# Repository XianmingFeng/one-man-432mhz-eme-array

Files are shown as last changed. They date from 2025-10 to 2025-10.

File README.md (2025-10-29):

# Portable 432MHz (70cm) EME Yagi Array

**A lightweight, tool-less, single-person-portable 2x2x14-element Yagi array for 432 MHz EME operations.**

---

[中文](/README_zh.md) | [Deutsche](/README_de.md) | [日本語](/README_ja.md)

## Overview

This project provides an open-source design for a 432 MHz (70cm) EME (Earth-Moon-Earth) antenna array. 

The motivation for this design stems from a personal need: the inability to install permanent antennas at home required all amateur radio equipment to be designed around portability. This antenna system is the solution for operators who must travel to the field to get on the air.

While traditional EME arrays are often large and permanently installed, this design focuses on achieving the minimum required gain for EME while prioritizing **portability, light weight, and rapid, single-person operation.**

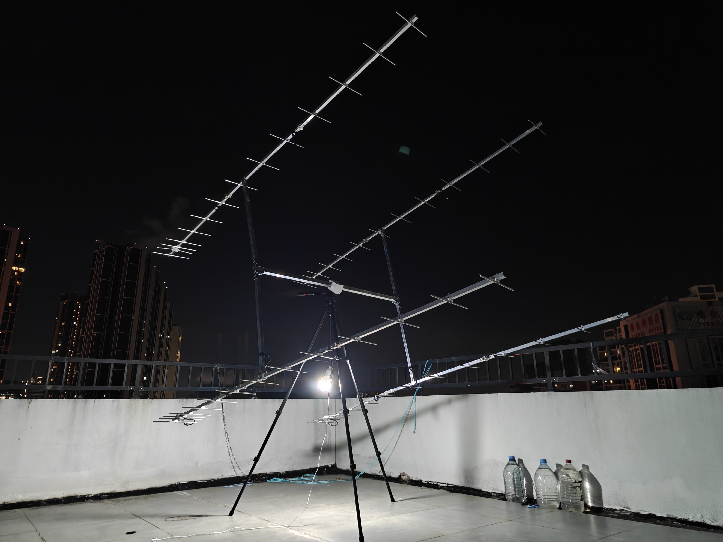
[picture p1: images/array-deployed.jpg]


## Proven Field Use & Air Travel

This system is not just a concept. Its usability was successfully confirmed during the **VK9QO Christmas Island DXpedition in 2025**.

The entire system is compliant with air travel requirements and can be checked as luggage. This makes it an ideal and proven solution for "Rovers" and DXpeditioners who wish to carry high-gain equipment to remote or rare DXCC entities to conduct EME operations.

## Key Features

* **Single-Person Portability:** The total weight of the entire array system, including the carrying bag, is **under 10 kg**.
* **Compact Storage:** All components are designed to be stored in a single fishing rod bag, making it easy for one person to carry.
* **Tool-less Assembly:** No tools (screwdrivers, wrenches, etc.) are required for field setup or teardown. The entire process can be completed by hand.
* **Rapid Deployment & Takedown:** The design is optimized for speed. This is achieved by:
    * Minimizing the number of loose parts.
    * Keeping most components connected as a single unit during storage.
    * Utilizing a simple "unfold-and-lock" and "unlock-and-fold" mechanism for deployment and retraction.

## Design Philosophy: Accessibility & Low Cost

A primary goal of this project is to enable anyone to easily build this antenna system. The design intentionally avoids complex machining processes (like CNC milling) to lower the barrier to entry.

Builders should be able to complete the entire antenna with only the most basic tools:
* Hand drill (pistol drill)
* Hand saw
* Manual rivet gun
* Pipe bender
* 3D Printer (All required `.step` files are available in the [`/CAD/3d_print`](/CAD/3d_print) directory)

**A note on 3D Printers:** We understand that not everyone owns a 3D printer. However:
1.  The accessibility and affordability of a home 3D printer are significantly higher than that of a home CNC machine.
2.  Even if you don't own one, using a 3D printing service is vastly more cost-effective and accessible than commissioning CNC machined parts.

## 3D Printing Guidelines

All 3D printed parts are located in the `/CAD/3d_print` directory.

### General Recommendations
Most parts function as mechanical components and are under moderate stress. The following general settings are recommended for strength and durability:

* **Material:** PETG (or ABS/ASA for better weather/UV resistance)
* **Layer Height:** 0.2mm
* **Wall Thickness:** 4 Layers
* **Infill Density:** 25% (or higher)
* **Infill Pattern:** Cross Hatch / Gyroid / or similar strong pattern

### **Critical Instructions**
**Each 3D print part subdirectory (e.g., `/CAD/3d_print/feed_box/`, `/CAD/3d_print/element_mount/`) now contains its own detailed, multi-lingual `README.md` file.**

You **MUST** read the specific `README.md` file in each part's directory before printing. These files contain essential, part-specific instructions for:
* Print Orientation
* Support settings (e.g., which parts require supports and which must not have them)
* Part-specific hardware (like heat-set inserts)

Failure to follow these part-specific instructions may result in parts that do not fit or function correctly.

## Aluminum Pipe Machining

All CAD files for the 6063 aluminum alloy tubes are located in the `/CAD/aluminum_pipe` directory. These parts form the foldable Yagi booms and the main H-frame.

### Manufacturing Methods
* **1. Manual (DIY) Machining:** Parts can be cut and drilled by hand. For this method, it is **ESSENTIAL** to 3D print and use the drilling jigs found in `/CAD/3d_print/drilling_jig/` to ensure all hinge and latch holes are aligned correctly.
* **2. Professional (CNC) Machining:** The provided `.step` files are CAM-ready and can be sent directly to a machining service for laser cutting or CNC milling.

### **Critical Instructions**
**A detailed, multi-lingual `README.md` with a full parts list, cutting dimensions, and drilling locations is located inside the [`/CAD/aluminum_pipe/`](/CAD/aluminum_pipe/) directory.**

You **MUST** read this file before cutting or drilling any metal. It contains all necessary specifications for the Yagi booms and H-frame components.

## Assembly Instructions

A step-by-step guide covering component fabrication (3D printing, aluminum machining), component preparation (coax cables), and sub-assembly (feed boxes) is now available.

**Please refer to the detailed Assembly Guide:**
**[`/instruction/README.md`](/instruction/README.md)**

This guide must be followed in order, as some steps produce tools required for later steps. The guide currently covers fabrication and initial sub-assemblies; final assembly steps will be added later.

## Technical Specifications

* **Band:** 432 MHz (70cm)
* **Array Configuration:** 2x2x14-element Yagi array (Four 14-element Yagis stacked in a 2x2 grid).
* **Polarization:** Horizontal.
* **Stacking Frame:** Custom H-frame.

### Theoretical Performance (Simulated)

**Single 14-el Yagi:**
* **Gain:** 16.38 dBi
* **Front-to-Back Ratio:** 33.02 dB
* **3dB Beamwidth (Horizontal):** 30.8°
* **3dB Beamwidth (Vertical):** 29.2°

**Full 2x2 Array:**
* **Gain:** 22.32 dBi
* **Front-to-Back Ratio:** 33.29 dB
* **3dB Beamwidth (Horizontal):** 14°
* **3dB Beamwidth (Vertical):** 13.2°
* **Antenna Temperature ($T_{ant}$):** 74.3 K
* **G/T Ratio:** 3.6 dB
> *Performance figures ($T_{ant}$, G/T) calculated assuming $T_{sky}$ = 27 K and $T_{earth}$ = 1800 K.*

## Mounting System (Tripod)

The array system is designed to be mounted on a standard tripod. The connection is made using the 3D printed part **`spearder_mount`** (files available in `/CAD/3d_print`).

This mount connects the array's H-frame to a tripod head's quick-release (QR) plate.

**Quick-Release Plate Requirements:**
The `spearder_mount` part is designed to be versatile. It is compatible with any long-slot style QR plate that meets these criteria:
* **Length:** Greater than 80mm.
* **Mounting:** Uses a long slot for the bolt (not a single fixed-position hole).
* **Bolt:** Compatible with a standard 1/4" (imperial) tripod bolt.

*As an example, the author uses a 38mm wide Arca-Swiss style QR plate paired with a fluid video head.*

**Tripod Recommendation:**
It is highly recommended to use a tripod with a **minimum height of 1.8 meters (approx. 6 feet)**.

* **Reason:** A tripod that is too short will cause the tail end of the antenna array to hit or drag on the ground when rotating to high elevation angles (e.g., tracking the moon).

## Design Details

### H-Frame Stacking System

The H-frame used to stack the four Yagis is designed for tool-less, rapid deployment. Its design is inspired by the folding leg mechanism of a portable table. This concept allows the frame to be deployed and locked into place, or unlocked and folded for storage, in seconds.

*The initial idea for this folding H-frame concept came from **BI1QGX**.*

### Modified 14-Element Yagi

The basic design of the 14-element Yagi is based on the **[GTV 70-14m by DG7YBN](https://dg7ybn.de/432MHz/GTV70_14.htm)**.
#### Electrical Design & Boom Correction

The electrical design adopts the data from DG7YBN and applies a Boom Correction (BC) factor to compensate for the effects of the conductive 20x20x1mm square aluminum boom. The elements are mounted 5mm above the boom (distance from the element's bottom to the boom's top surface).

The table below shows the original NEC free-space length (FL NEC), the final boom-corrected length (BC), and the required half-length (Half L) for element construction.

| \[mm\] | Diam | Pos Boom | FL NEC | BC | Half L |
|:---|:-----|:---|:---|:---|:---|
| Refl | 8 | 40 | 328 | 330.7 | 165.35 |
| DE | 10 | 144.5 | 313.4  | 316.1 | 158.05 |
| D1 | 8 | 193 | 309 | 311.7 | 155.85 |
| D2 | 8 | 286 | 304 | 306.7 | 153.35 |
| D3 | 8 | 468 | 292 | 294.7 | 147.35 |
| D4 | 8 | 681 | 286 | 288.7 | 144.35 |
| D5 | 8 | 928 | 282 | 284.7 | 142.35 |
| D6 | 8 | 1192 | 279 | 281.7 | 140.85 |
| D7 | 8 | 1477 | 274.5  | 277.2 | 138.6  |
| D8 | 8 | 1764 | 271 | 273.7 | 136.85 |
| D9 | 8 | 2054 | 268 | 270.7 | 135.35 |
| D10 | 8 | 2345 | 266 | 268.7 | 134.35 |
| D11 | 8 | 2627 | 264 | 266.7 | 133.35 |
| D12 | 8 | 2860 | 256 | 258.7 | 129.35 |

For a detailed explanation of the Boom Correction methodology, please visit [DG7YBN's BC page](https://dg7ybn.de/BC_numbers/BC.htm).

#### Mechanical Optimizations

In addition to the electrical design, this project introduces significant *mechanical* modifications to the original design to optimize it for portability and rapid assembly. These optimizations include:
* Redesigned boom segments and folding hinges.
* A new feedbox design.
* A specialized element mounting system (see below).

#### Element Mount (The `element_mount` part)

A key feature of this design is the 3D-printed element mount (`element_mount.step`) used for all parasitic elements (reflectors and directors).

* **Dual-Slot Design:** The part features two slots. One slot holds the element perpendicular to the boom for operation. A second slot, at a near-perpendicular angle, is used to hold the element in its folded (stowed) position.
* **Interference-Free Storage:** The "storage" slot is intentionally offset by a small angle (the `parking_angle`). This ensures that when folded, the elements do not lie perfectly parallel to the boom, preventing them from interfering with adjacent elements or the mounting bolt heads.
* **General-Purpose Parametric Design:** This element mount is a universal, general-purpose design, suitable for many Yagi projects using square booms and round elements. It has been released as its own **parametric OpenSCAD project**.

For full details, parameters (to adapt it for your own boom size, element diameter, storage angle, etc.), and `.scad` files, please see the dedicated project repository:
**[https://github.com/XianmingFeng/yagi_element_mounting](https://github.com/XianmingFeng/yagi_element_mounting)**

## Bill of Materials (BOM)

This is a partial BOM and will be updated as the project progresses.

| Category | Part | Qty |
|:---|:---|:----|
| Yagi Elements & Feedbox | `element_mount` 3D Printed Part | 52  |
| | Socket Head Cap Screw (Half-thread) M3x40 | 52  |
| | Wing Nut M3 | 56  |
| | `feed_box_front` 3D Printed Part | 4 |
| | `feed_box_middle` 3D Printed Part | 4 |
| | `feed_box_rear` 3D Printed Part | 4 |
| | `feed_box_isolator` 3D Printed Part | 4 |
| | Button Head Hex Socket Screw M3x8 | 8 |
| | Socket Head Cap Screw M3x40 | 4 |
| | Knurled Brass Nut (Heat-set Insert) M3x4x5 | 36  |
| | Socket Head Cap Screw M3x24 | 28  |
| | Copper Terminal Lug RNB-1.25-4 | 16  |
| | | |
| Yagi Boom Folding Mechanism | Small Double Spring Toggle Latch (No lock hole) | 8 |
| | Latch Catch A320B-0-2 | 8 |
| | Iron Gooseneck Hinge 20mm | 16  |
| | Round Head Blind Rivet M4x5 | 96  |
| | `boom_hinge_cap_front` 3D Printed Part | 8 |
| | `boom_hinge_cap_rear` 3D Printed Part | 8 |
| Boom-to-H-Frame Quick Release | Square Tube 2-Way T-Connector 25x25 | 4 |
| | Wing Bolt M6x30 | 4 |
| | Wing Nut M6 | 4 |
| | V-Spring Clip F5mm Single Pin (Hollow), L:37mm H:8mm | 4 |
| | Round Head Blind Rivet M5x8 | 8 |
| H-Frame Folding Mechanism | 90-Degree Folding Table Leg Hinge, Mini Size, Right  | 2 |
| | 90-Degree Folding Table Leg Hinge, Mini Size, Left | 2 |
| | Round Head Blind Rivet M5x6 | 24  |

## Repository Contents

* **`/CAD`**: Contains all 3D model files.
    * **`/CAD/3d_print`**: Contains `.step` files for all 3D printed parts. Each subdirectory (e.g., `feed_box/`, `element_mount/`) also contains a specific, multi-lingual `README.md` with detailed printing instructions. See the **3D Printing Guidelines** section above.
    * **`/CAD/aluminum_pipe`**: Contains `.step` files for all aluminum tube/pipe components. This directory now also contains a detailed **`README.md`** with machining instructions. See the **Aluminum Pipe Machining** section above.
* **`/images`**: Contains images used in this README.
* **`/instruction`**: Contains the detailed step-by-step assembly guide (`README.md` and translations).
* **`LICENSE`**: The project's open-source license file.
* **`README.md`**: This file (English).
* **`README_zh.md`**: Chinese translation.
* **`README_de.md`**: German translation.
* **`README_ja.md`**: Japanese translation.

## Project Status

* **Available Now:**
    * Initial 3D CAD files (`.step`) for all 3D printed parts and aluminum components are available in the `/CAD` directory.
    * Detailed, part-specific printing instructions are available in each `/CAD/3d_print` subdirectory.
    * Detailed machining instructions for aluminum parts are available in the `/CAD/aluminum_pipe/` directory.
    * Partial assembly instructions (covering fabrication and initial sub-assemblies) are available in the `/instruction/` directory.
    * Electrical design data (element lengths and positions) are in this README.
    * A partial Bill of Materials (BOM) is now available.
* **To Be Added:**
    * Complete Bill of Materials (BOM) (e.g., specific aluminum pipe sizes, screws).
    * Complete Assembly Instructions (final assembly, phasing lines) & Photos/Videos.
    * Simulation Files (e.g., EZNEC/4nec2).
    * Print-ready `.stl` files (recommended).
## Acknowledgements

* **DG7YBN** for the original [GTV 70-14m](https://dg7ybn.de/432MHz/GTV70_14.htm) antenna design and [Boom Correction methodology](https://dg7ybn.de/BC_numbers/BC.htm).
* **BI1QGX** for the foundational concept of the folding H-frame.

## License

Shield: [][cc-by-nc-sa]

This work is licensed under a
[Creative Commons Attribution-NonCommercial-ShareAlike 4.0 International License][cc-by-nc-sa].

[][cc-by-nc-sa]

[cc-by-nc-sa]: http://creativecommons.org/licenses/by-nc-sa/4.0/
[cc-by-nc-sa-image]: https://licensebuttons.net/l/by-nc-sa/4.0/88x31.png
[cc-by-nc-sa-shield]: https://img.shields.io/badge/License-CC%20BY--NC--SA%204.0-lightgrey.svg

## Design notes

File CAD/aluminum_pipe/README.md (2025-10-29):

# Aluminum Pipe Machining Instructions

[English](#english) | [中文 (Chinese)](#中文-chinese) | [Deutsche (German)](#deutsche-german) | [日本語 (Japanese)](#日本語-japanese)

---

## English

### Overview
This directory contains all `.step` CAD files for the 6063 aluminum alloy tubes required for the antenna array. These components form the foldable Yagi booms and the main H-shaped stacking frame.

All parts must be precisely cut to length and drilled. The provided `.step` files are dimensionally accurate and can be used for both manual (DIY) manufacturing and professional CAM processing.

### General Manufacturing Recommendations

There are two primary methods to manufacture these parts:

**1. Manual (DIY) Machining**
* Parts can be cut to length with a hand saw and drilled using a hand drill or drill press.
* **Drilling Jigs (CRITICAL):** For all critical hole alignments (e.g., hinge and latch holes on the booms, hinge holes on the H-frame), it is **ESSENTIAL** to 3D print and use the corresponding drilling jigs available in the `../3d_print/drilling_jig/` directory. This ensures all folding components align and operate smoothly.
    * Use `hinge_drill_jig.step` for Yagi boom sections.
    * Use `mast_drill_jig.step` for the vertical masts.
    * Use `spreader_drill_jig.step` for the horizontal spreader.

**2. Professional (CNC) Machining**
* The `.step` files provided are **CAM-ready**.
* You can send these files directly to a machining service (e.g., for laser cutting or CNC milling) for professional and highly accurate manufacturing.

---

### Bill of Materials (BOM) & Machining Details

#### Module 1: Yagi Antenna Booms (4 Assemblies total)
These components assemble to create four individual, three-section, foldable 14-element Yagis.

| Part File (STEP) | Material | Qty (per Array) | Description & Machining Notes |
|:---|:---|:---|:---|
| `yagi_boom_front.step`  | 20x20x1mm Square Tube | 4 | **Front Boom Section.** <br> • **Element Holes:** Spaced holes for antenna elements. <br> • **Hinge/Latch Holes:** Densely clustered holes at the ends for folding hinges and latches. <br> • **Jig:** Must use `hinge_drill_jig.step` for manual drilling of hinge/latch holes.  |
| `yagi_boom_middle.step` | 20x20x1mm Square Tube | 4 | **Middle Boom Section.** <br> • **Element Holes:** Spaced holes for antenna elements. <br> • **Hinge/Latch Holes:** Densely clustered holes at the ends for folding hinges and latches. <br> • **Jig:** Must use `hinge_drill_jig.step` for manual drilling of hinge/latch holes. |
| `yagi_boom_rear.step` | 20x20x1mm Square Tube | 4 | **Rear Boom Section.** <br> • **Element Holes:** Spaced holes for antenna elements. <br> • **Hinge/Latch Holes:** Densely clustered holes at the ends for folding hinges and latches. <br> • **Jig:** Must use `hinge_drill_jig.step` for manual drilling of hinge/latch holes. |

---
#### Module 2: H-Frame (Stacking Frame) (1 Assembly total)
These components form the main folding H-frame used to stack the four Yagi antennas.

| Part File (STEP) | Material | Qty (per Array) | Description & Machining Notes |
|:---|:---|:---|:---|
| `stacking_vertical_mast.step` | 25x25x1mm Square Tube | 4 | **Vertical Mast.** <br> • These four tubes form the two vertical "legs" of the H-frame. <br> • **Hinge Holes:** Holes at one end are for mounting the 90-degree folding hinges. <br> • **Jig:** Highly recommend using `mast_drill_jig.step` for manual drilling. |
| `stacking_horizontal_spreader.step` | 30x30x1mm Square Tube | 1 | **Horizontal Spreader.** <br> • This single, heavy-duty tube is the central horizontal spine that bears the weight of the entire array. <br> • **Hinge Holes:** Holes at both ends are for mounting the 90-degree folding hinges. <br> • **Jig:** Highly recommend using `spreader_drill_jig.step` for manual drilling. |

---
#### Module 3: Interface & Adapter Parts
This part serves as a shim or sleeve to ensure a tight fit between the booms and the mounting connectors.

| Part File (STEP) | Material | Qty (per Array) | Description & Machining Notes |
|:---|:---|:---|:---|
| `boom_sleeve.step` | 25x25x2.5mm Square Tube | 8 | **Boom Sleeve / Adapter.** <br> • This part adapts the 20x20mm Yagi boom to fit snugly inside the 25x25mm quick-release T-connectors. <br> • **Manufacture:** Simply cut the 25x25x2.5mm tube in half lengthwise (longitudinally). <br> • **Precision:** No high precision is required for this part. |

---
---

## 中文 (Chinese)

### 概览
此目录包含本天线阵列所需的所有 6063 铝合金管材的 `.step` CAD 文件。这些组件用于构成可折叠的八木天线主梁 (Yagi Booms) 和 H 型主支撑框架 (H-frame)。

所有零件都必须被精确地切割到指定长度并钻孔。所提供的 `.step` 文件尺寸精确，既可用于手动 (DIY) 制造，也可直接用于专业的 CAM 加工。

### 通用制造建议

有两种主要方法来制造这些零件：

**1. 手动 (DIY) 加工**
* 可以使用手锯切割长度，并使用手电钻或台钻钻孔。
* **钻孔夹具 (关键):** 对于所有关键的孔位对齐（例如，主梁上的铰链和锁扣孔，H 型框架上的铰链孔），**必须** 3D 打印并使用 `../3d_print/drilling_jig/` 目录中相应的钻孔夹具。这能确保所有折叠部件正确对齐且运行顺畅。
    * 八木主梁 (Yagi boom) 请使用 `hinge_drill_jig.step`。
    * 垂直梁 (Vertical mast) 请使用 `mast_drill_jig.step`。
    * 水平梁 (Horizontal spreader) 请使用 `spreader_drill_jig.step`。

**2. 专业 (CNC) 加工**
* 此目录中提供的 `.step` 文件是**符合 CAM 加工标准**的。
* 您可以将这些文件直接发送给机械加工服务商 (例如，激光切割或 CNC 铣削)，以进行专业且高精度的制造。

---

### 物料清单 (BOM) 与加工详情

#### 模块 1: 八木天线主梁 (Yagi Booms) (共 4 套)
这些组件用于组装成四根独立、三段式、可折叠的 14 单元八木天线。

| 零件文件 (STEP) | 材料 | 阵列所需数量 | 描述与加工说明 |
|:---|:---|:---|:---|
| `yagi_boom_front.step`  | 20x20x1mm 方管 | 4 | **主梁 - 前段。** <br> • **振子孔:** 沿主梁分布的孔洞，用于安装天线振子。 <br> • **铰链/锁扣孔:** 两端密集的孔洞，用于安装折叠铰链和弹簧锁扣。 <br> • **夹具:** 手动钻铰链/锁扣孔时，**必须**使用 `hinge_drill_jig.step`。 |
| `yagi_boom_middle.step` | 20x20x1mm 方管 | 4 | **主梁 - 中段。** <br> • **振子孔:** 沿主梁分布的孔洞，用于安装天线振子。 <br> • **铰链/锁扣孔:** 两端密集的孔洞，用于安装折叠铰链和弹簧锁扣。 <br> • **夹具:** 手动钻铰链/锁扣孔时，**必须**使用 `hinge_drill_jig.step`。 |
| `yagi_boom_rear.step` | 20x20x1mm 方管 | 4 | **主梁 - 后段。** <br> • **振子孔:** 沿主梁分布的孔洞，用于安装天线振子。 <br> • **铰链/锁扣孔:** 两端密集的孔洞，用于安装折叠铰链和弹簧锁扣。 <br> • **夹具:** 手动钻铰链/锁扣孔时，**必须**使用 `hinge_drill_jig.step`。 |

---
#### 模块 2: H型框架 (Stacking Frame) (共 1 套)
这些组件构成了用于堆叠四根八木天线的主折叠 H 型框架。

| 零件文件 (STEP) | 材料 | 阵列所需数量 | 描述与加工说明 |
|:---|:---|:---|:---|
| `stacking_vertical_mast.step` | 25x25x1mm 方管 | 4 | **H型架垂直梁。** <br> • 这四根管子组成了 H 型框架的两条垂直“腿”。 <br> • **铰链孔:** 一端的孔洞用于安装 90 度折叠“桌腿”铰链。 <br> • **夹具:** 手动钻孔时，**强烈建议**使用 `mast_drill_jig.step`。 |
| `stacking_horizontal_spreader.step` | 30x30x1mm 方管 | 1 | **H型架水平梁。** <br> • 这根单独的、加强的管材是 H 型架的中央水平脊柱，承载整个阵列的重量。 <br> • **铰链孔:** 两端的孔洞用于安装 90 度折叠“桌腿”铰链。 <br> • **夹具:** 手动钻孔时，**强烈建议**使用 `spreader_drill_jig.step`。 |

---
#### 模块 3: 转接与适配零件
此零件用作垫片或套筒，以确保主梁和安装连接件之间紧密配合。

| 零件文件 (STEP) | 材料 | 阵列所需数量 | 描述与加工说明 |
|:---|:---|:---|:---|
| `boom_sleeve.step` | 25x25x2.5mm 方管 | 8 | **主梁套筒 / 转接件。** <br> • 用于将 20x20mm 的八木主梁适配，使其能紧密安装在 25x25mm 内径的快装 T 型连接件中。 <br> • **制造:** 只需将 25x25x2.5mm 的管材沿长度方向（纵向）锯成两半。 <br> • **精度:** 此零件**没有高精度要求**。 |

---
---

## Deutsche (German)

### Übersicht
Dieses Verzeichnis enthält alle `.step` CAD-Dateien für die 6063-Aluminiumlegierungsrohre, die für das Antennen-Array benötigt werden. Diese Komponenten bilden die faltbaren Yagi-Antennenbäume und den H-förmigen Haupt-Stacking-Rahmen.

Alle Teile müssen präzise auf Länge zugeschnitten und gebohrt werden. Die bereitgestellten `.step`-Dateien sind maßgenau und können sowohl für die manuelle (DIY) Fertigung als auch für die professionelle CAM-Verarbeitung verwendet werden.

### Allgemeine Fertigungsempfehlungen

Es gibt zwei Hauptmethoden, um diese Teile herzustellen:

**1. Manuelle (DIY) Bearbeitung**
* Teile können mit einer Handsäge auf Länge geschnitten und mit einer Handbohrmaschine oder Ständerbohrmaschine gebohrt werden.
* **Bohrschablonen (ENTSCHEIDEND):** Für alle kritischen Lochausrichtungen (z. B. Scharnier- und Riegellöcher an den Booms, Scharnierlöcher am H-Rahmen) ist es **UNERLÄSSLICH**, die entsprechenden Bohrschablonen aus dem Verzeichnis `../3d_print/drilling_jig/` in 3D zu drucken und zu verwenden. Dies stellt sicher, dass alle Klappkomponenten ausgerichtet sind und reibungslos funktionieren.
    * Verwenden Sie `hinge_drill_jig.step` für die Yagi-Boom-Abschnitte.
    * Verwenden Sie `mast_drill_jig.step` für die vertikalen Masten.
    * Verwenden Sie `spreader_drill_jig.step` für die horizontale Traverse.

**2. Professionelle (CNC) Bearbeitung**
* Die bereitgestellten `.step`-Dateien sind **CAM-fähig**.
* Sie können diese Dateien direkt an einen Bearbeitungsservice (z. B. zum Laserschneiden oder CNC-Fräsen) senden, um sie professionell und präzise fertigen zu lassen.

---

### Stückliste (BOM) & Bearbeitungsdetails

#### Modul 1: Yagi-Antennenbäume (Insgesamt 4 Baugruppen)
Diese Komponenten werden zu vier einzelnen, dreiteiligen, faltbaren 14-Element-Yagis zusammengebaut.

| Bauteildatei (STEP) | Material | Menge (pro Array) | Beschreibung & Bearbeitungshinweise |
|:---|:---|:---|:---|
| `yagi_boom_front.step`  | 20x20x1mm Vierkantrohr | 4 | **Vorderer Boom-Abschnitt.** <br> • **Elementlöcher:** Löcher zur Montage der Antennenelemente. <br> • **Scharnier-/Riegellöcher:** Dichte Lochgruppen an den Enden für Klappscharniere und Riegel. <br> • **Bohrschablone:** Beim manuellen Bohren der Scharnier-/Riegellöcher muss `hinge_drill_jig.step` verwendet werden.  |
| `yagi_boom_middle.step` | 20x20x1mm Vierkantrohr | 4 | **Mittlerer Boom-Abschnitt.** <br> • **Elementlöcher:** Löcher zur Montage der Antennenelemente. <br> • **Scharnier-/Riegellöcher:** Dichte Lochgruppen an den Enden für Klappscharniere und Riegel. <br> • **Bohrschablone:** Beim manuellen Bohren der Scharnier-/Riegellöcher muss `hinge_drill_jig.step` verwendet werden. |
| `yagi_boom_rear.step` | 20x20x1mm Vierkantrohr | 4 | **Hinterer Boom-Abschnitt.** <br> • **Elementlöcher:** Löcher zur Montage der Antennenelemente. <br> • **Scharnier-/Riegellöcher:** Dichte Lochgruppen an den Enden für Klappscharniere und Riegel. <br> • **Bohrschablone:** Beim manuellen Bohren der Scharnier-/Riegellöcher muss `hinge_drill_jig.step` verwendet werden.  |

---
#### Modul 2: H-Rahmen (Stacking Frame) (Insgesamt 1 Baugruppe)
Diese Komponenten bilden den faltbaren Haupt-H-Rahmen, der zur Stapelung der vier Yagi-Antennen verwendet wird.

| Bauteildatei (STEP) | Material | Menge (pro Array) | Beschreibung & Bearbeitungshinweise |
|:---|:---|:---|:---|
| `stacking_vertical_mast.step` | 25x25x1mm Vierkantrohr | 4 | **Vertikaler Mast.** <br> • Diese vier Rohre bilden die beiden vertikalen "Beine" des H-Rahmens. <br> • **Scharnierlöcher:** Löcher an einem Ende zur Montage der 90-Grad-Klappscharniere. <br> • **Bohrschablone:** Beim manuellen Bohren wird dringend empfohlen, `mast_drill_jig.step` zu verwenden. |
| `stacking_horizontal_spreader.step` | 30x30x1mm Vierkantrohr | 1 | **Horizontale Traverse.** <br> • Dieses einzelne, hochbelastbare Rohr ist das zentrale horizontale Rückgrat, das das Gewicht des gesamten Arrays trägt. <br> • **Scharnierlöcher:** Löcher an beiden Enden zur Montage der 90-Grad-Klappscharniere. <br> • **Bohrschablone:** Beim manuellen Bohren wird dringend empfohlen, `spreader_drill_jig.step` zu verwenden. |

---
#### Modul 3: Schnittstellen- & Adapterteile
Dieses Teil dient als Distanzstück oder Hülse, um einen festen Sitz zwischen den Booms und den Montageverbindern zu gewährleisten.

| Bauteildatei (STEP) | Material | Menge (pro Array) | Beschreibung & Bearbeitungshinweise |
|:---|:---|:---|:---|
| `boom_sleeve.step`  | 25x25x2.5mm Vierkantrohr | 8 | **Boom-Hülse / Adapter.** <br> • Passt den 20x20mm Yagi-Boom an, damit er fest in die 25x25mm Schnellverschluss-T-Verbinder passt. <br> • **Herstellung:** Das 25x25x2.5mm Rohr einfach der Länge nach halbieren. <br> • **Präzision:** Für dieses Teil ist keine hohe Präzision erforderlich. |

---
---

## 日本語 (Japanese)

### 概要
このディレクトリには、アンテナアレイに必要なすべての 6063 アルミニウム合金チューブの `.step` CADファイルが含まれています。これらのコンポーネントは、折りたたみ式の八木アンテナブームと、H型メイン・スタッキングフレームを構成します。

すべての部品は、指定された長さに正確に切断し、穴あけ加工する必要があります。提供される `.step` ファイルは寸法が正確であり、手動 (DIY) での製造と、専門的なCAM（キャム）加工の両方に使用できます。

### 一般的な製造推奨事項

これらの部品を製造するには、主に2つの方法があります。

**1. 手動 (DIY) 加工**
* 部品は手鋸で長さに切断し、ハンドドリルやボール盤で穴をあけることができます。
* **穴あけ治具 (重要):** すべての重要な穴の位置合わせ（例: ブームのヒンジやラッチの穴、Hフレームのヒンジ穴）には、`../3d_print/drilling_jig/` ディレクトリにある対応する穴あけ治具を3Dプリントして**必ず使用**してください。これにより、すべての折りたたみコンポーネントが正しく位置合わせされ、スムーズに動作することが保証されます。
    * 八木ブーム（Yagi boom）には `hinge_drill_jig.step` を使用します。
    * 垂直マスト（Vertical mast）には `mast_drill_jig.step` を使用します。
    * 水平スプレッダー（Horizontal spreader）には `spreader_drill_jig.step` を使用します。

**2. 専門業者 (CNC) 加工**
* 提供されている `.step` ファイルは**CAM対応**です。
* これらのファイルを（レーザーカットやCNCフライス加工などの）機械加工サービスに直接送信して、専門的かつ高精度に製造してもらうことができます。

---

### 部品表 (BOM) と加工詳細

#### モジュール 1: 八木アンテナブーム (Yagi Booms) (合計 4 セット)
これらのコンポーネントは、4本（それぞれ3セクションで構成される）の折りたたみ式14エレメント八木アンテナを組み立てるために使用されます。

| パーツファイル (STEP) | 材質 | アレイあたりの数量 | 説明と加工ノート |
|:---|:---|:---|:---|
| `yagi_boom_front.step`  | 20x20x1mm 角パイプ | 4 | **ブーム - フロントセクション。** <br> • **エレメント用の穴:** アンテナエレメント（素子）を取り付けるための穴。 <br> • **ヒンジ/ラッチ用の穴:** 両端に集中している穴は、折りたたみヒンジとラッチ用。 <br> • **治具:** 手動でヒンジ/ラッチの穴をあける際は、**必ず** `hinge_drill_jig.step` を使用してください。 |
| `yagi_boom_middle.step` | 20x20x1mm 角パイプ | 4 | **ブーム - ミドルセクション。** <br> • **エレメント用の穴:** アンテナエレメント（素子）を取り付けるための穴。 <br> • **ヒンジ/ラッチ用の穴:** 両端に集中している穴は、折りたたみヒンジとラッチ用。 <br> • **治具:** 手動でヒンジ/ラッチの穴をあける際は、**必ず** `hinge_drill_jig.step` を使用してください。  |
| `yagi_boom_rear.step` | 20x20x1mm 角パイプ | 4 | **ブーム - リアセクション。** <br> • **エレメント用の穴:** アンテナエレメント（素子）を取り付けるための穴。 <br> • **ヒンジ/ラッチ用の穴:** 両端に集中している穴は、折りたたみヒンジとラッチ用。 <br> • **治具:** 手動でヒンジ/ラッチの穴をあける際は、**必ず** `hinge_drill_jig.step` を使用してください。 |

---
#### モジュール 2: Hフレーム (Stacking Frame) (合計 1 セット)
これらのコンポーネントは、4本の八木アンテナをスタックするために使用される、メインの折りたたみ式Hフレームを構成します。

| パーツファイル (STEP) | 材質 | アレイあたりの数量 | 説明と加工ノート |
|:---|:---|:---|:---|
| `stacking_vertical_mast.step` | 25x25x1mm 角パイプ | 4 | **垂直マスト。** <br> • これら4本のパイプがHフレームの2本の垂直な「脚」を構成します。 <br> • **ヒンジ用の穴:** 一方の端にある穴は、90度折りたたみヒンジを取り付けるためのものです。 <br> • **治具:** 手動で穴をあける際は、`mast_drill_jig.step` の使用を**強く推奨**します。 |
| `stacking_horizontal_spreader.step` | 30x30x1mm 角パイプ | 1 | **水平スプレッダー。** <br> • この1本の頑丈なパイプは、アレイ全体の重量を支える中央の水平な背骨となります。 <br> • **ヒンジ用の穴:** 両端にある穴は、90度折りたたみヒンジを取り付けるためのものです。 <br> • **治具:** 手動で穴をあける際は、`spreader_drill_jig.step` の使用を**強く推奨**します。 |

---
#### モジュール 3: インターフェースとアダプター部品
この部品は、ブームと取り付けコネクタ間の確実な固定を保証するためのシム（詰め物）またはスリーブとして機能します。

| パーツファイル (STEP) | 材質 | アレイあたりの数量 | 説明と加工ノート |
|:---|:---|:---|:---|
| `boom_sleeve.step` | 25x25x2.5mm 角パイプ | 8 | **ブームスリーブ / アダプター。** <br> • 20x20mmの八木ブームを、内径25x25mmのクイックリリースT型コネクタにぴったりと適合させます。 <br> • **製造:** 25x25x2.5mmのパイプを長手方向に沿って半分に切断するだけです。 <br> • **精度:** この部品に**高い精度は要求されません**。 |

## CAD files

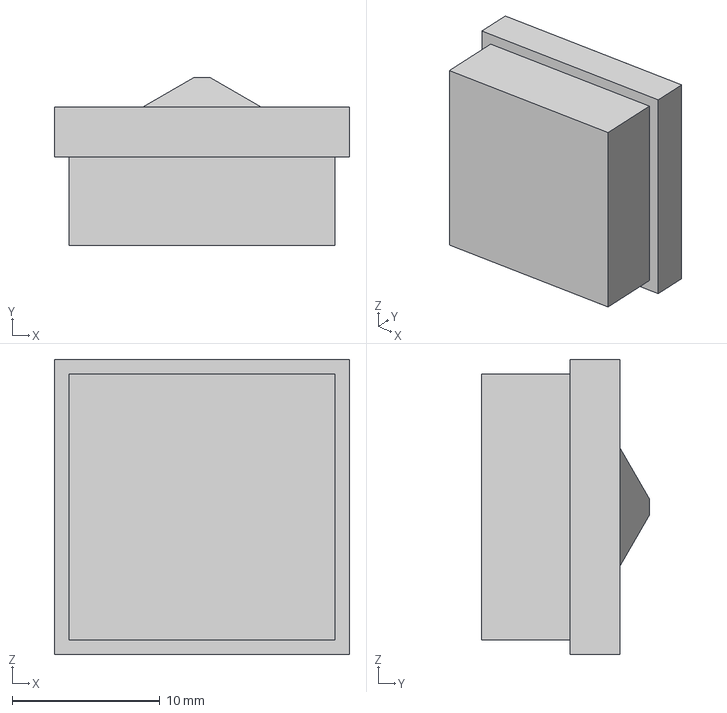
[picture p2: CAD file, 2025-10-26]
CAD/3d_print/boom_hinge/boom_hinge_cap_front.step
20.0 x 11.4 x 20.0 mm

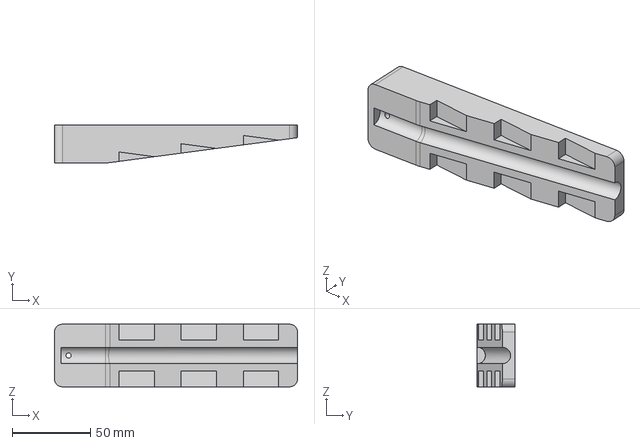
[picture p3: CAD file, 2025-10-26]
CAD/3d_print/drilling_jig/driven_element_drill_jig_upper.step
155.2 x 24.2 x 40.0 mm

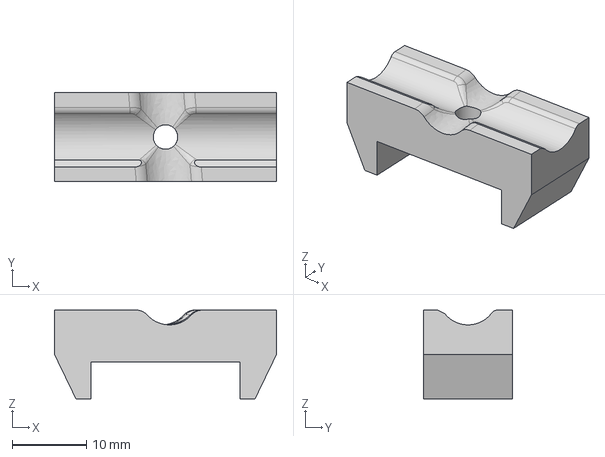
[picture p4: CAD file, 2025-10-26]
CAD/3d_print/element_mount/element_mount.step
30.0 x 12.0 x 12.0 mm

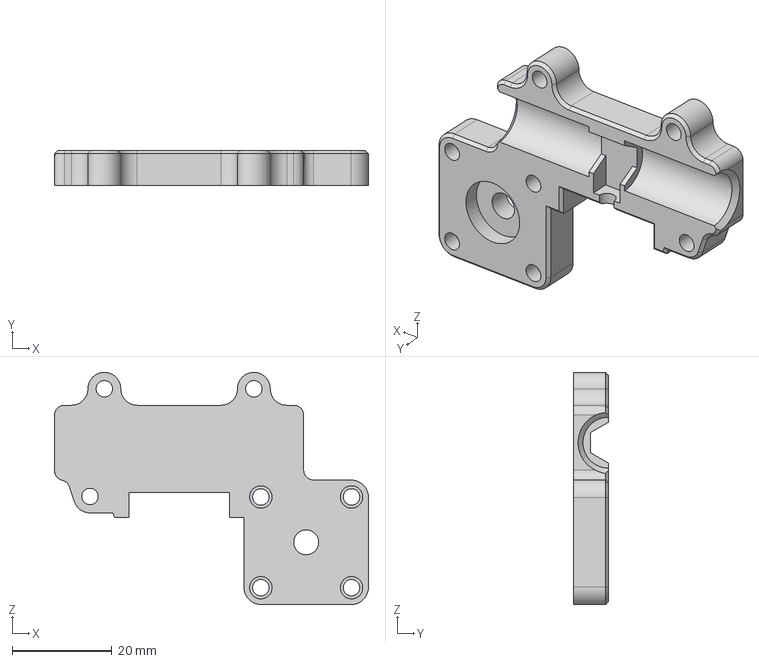
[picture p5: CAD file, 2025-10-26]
CAD/3d_print/feed_box/feed_box_rear.step
63.0 x 7.00 x 46.6 mm

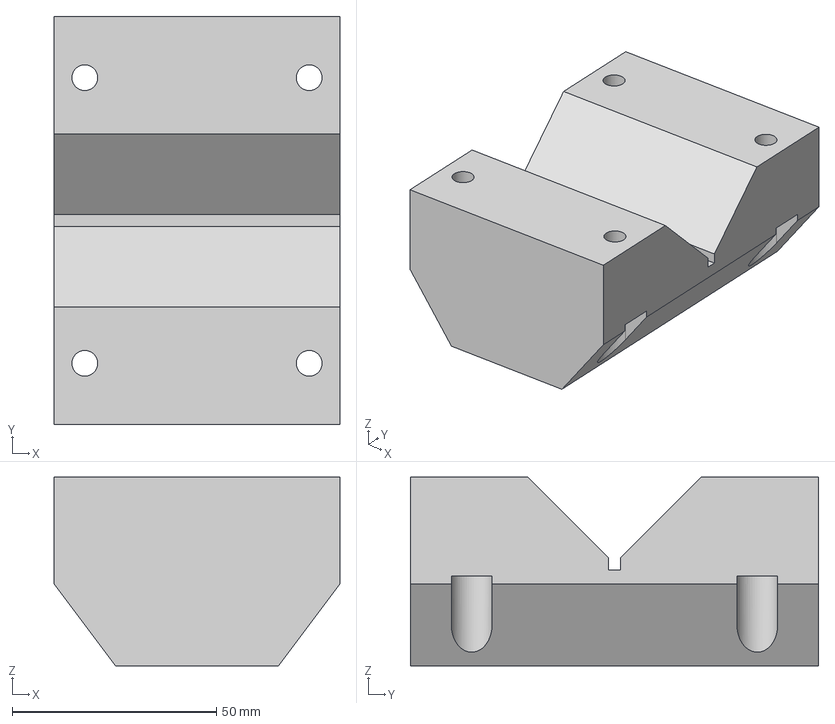
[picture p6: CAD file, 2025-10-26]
CAD/3d_print/spearder_mount/spearder_mount_lower.step
70.0 x 100.0 x 46.2 mm

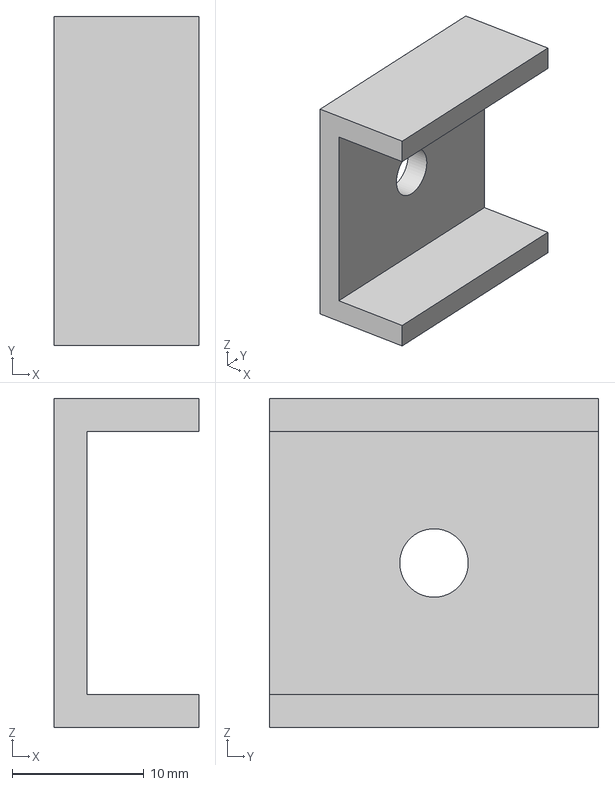
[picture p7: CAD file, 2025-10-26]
CAD/aluminum_pipe/boom_sleeve.step
11.0 x 25.0 x 25.0 mm

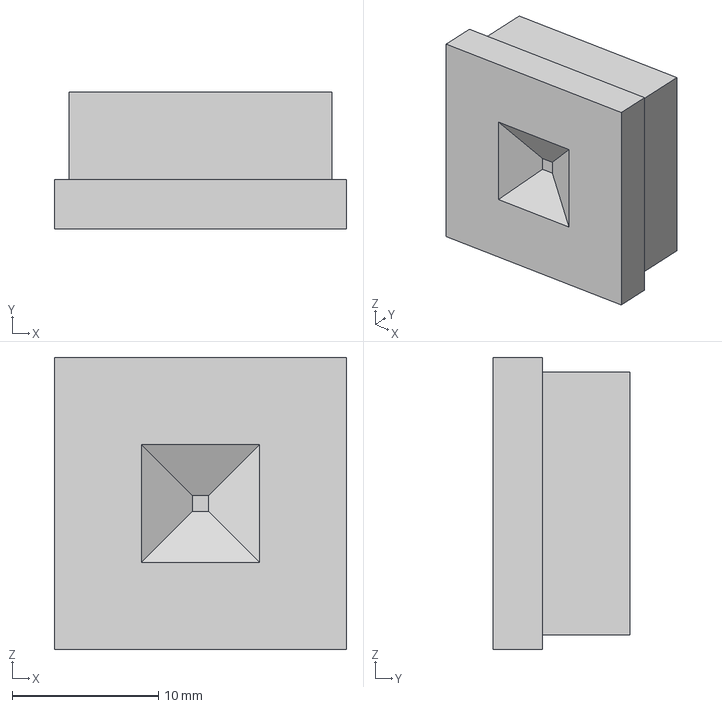
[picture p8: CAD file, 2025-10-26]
CAD/3d_print/boom_hinge/boom_hinge_cap_rear.step
20.0 x 9.40 x 20.0 mm

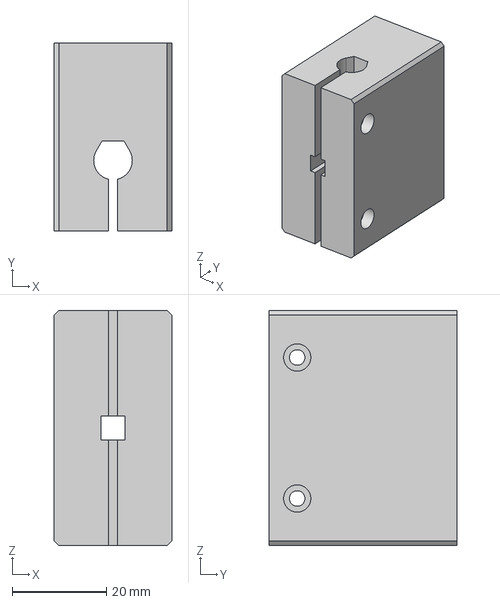
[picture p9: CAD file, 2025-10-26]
CAD/3d_print/drilling_jig/element_drill_jig.step
25.0 x 40.0 x 50.0 mm

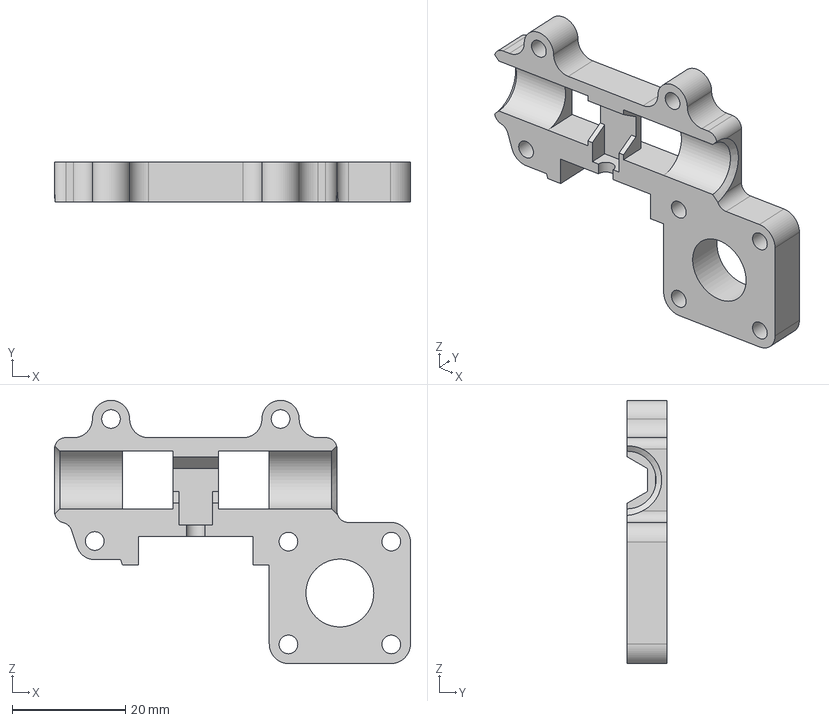
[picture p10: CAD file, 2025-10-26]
CAD/3d_print/feed_box/feed_box_middle.step
63.0 x 7.00 x 46.6 mm

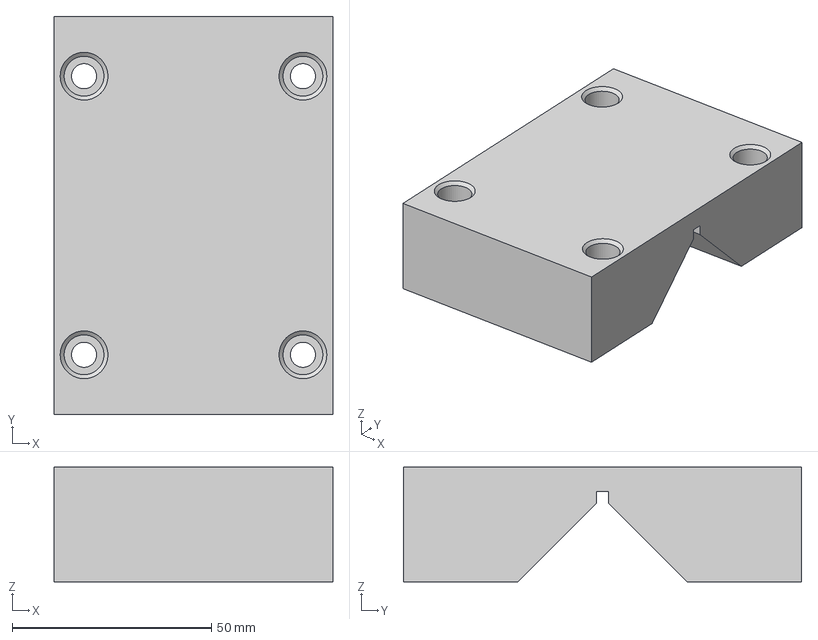
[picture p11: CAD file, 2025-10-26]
CAD/3d_print/spearder_mount/spearder_mount_upper.step
70.0 x 100.0 x 28.8 mm

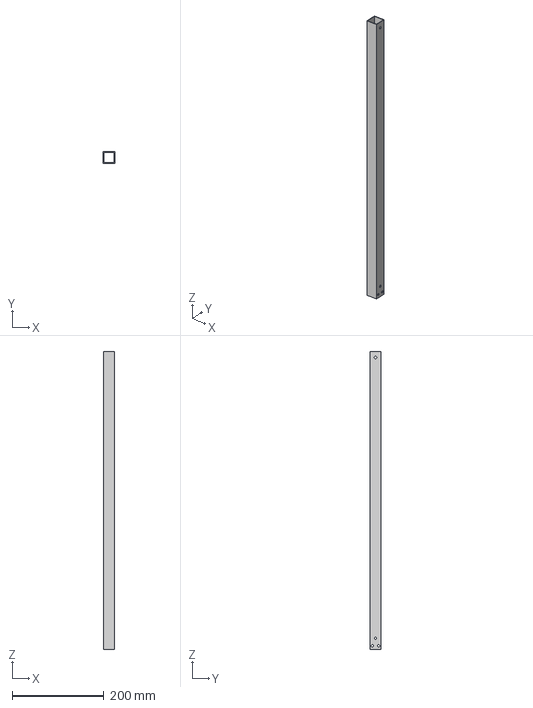
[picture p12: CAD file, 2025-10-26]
CAD/aluminum_pipe/stacking_vertical_mast.step
25.0 x 25.0 x 650.0 mm

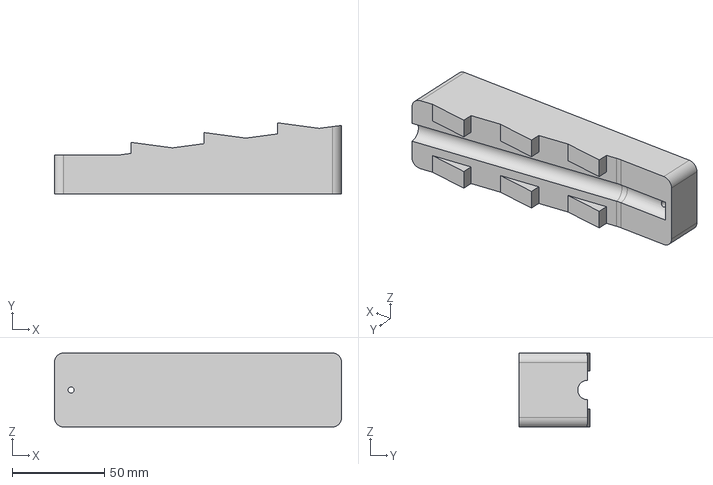
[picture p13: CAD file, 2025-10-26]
CAD/3d_print/drilling_jig/driven_element_drill_jig_lower.step
155.2 x 38.6 x 40.0 mm

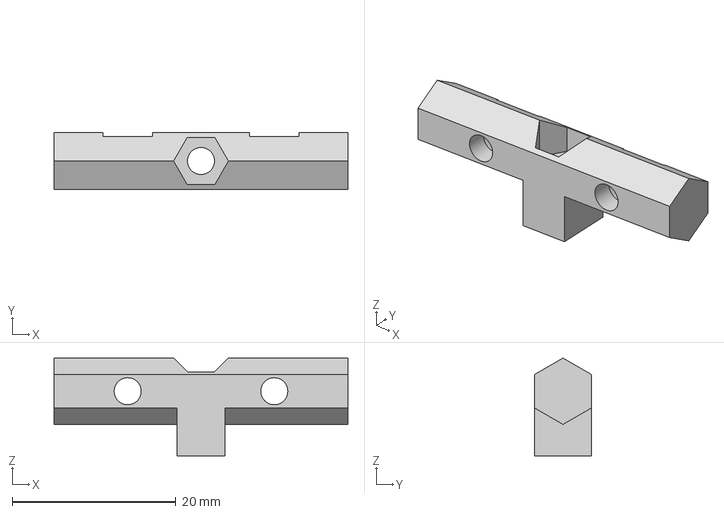
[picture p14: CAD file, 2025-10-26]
CAD/3d_print/feed_box/feed_box_isolator.step
35.9 x 7.01 x 11.9 mm

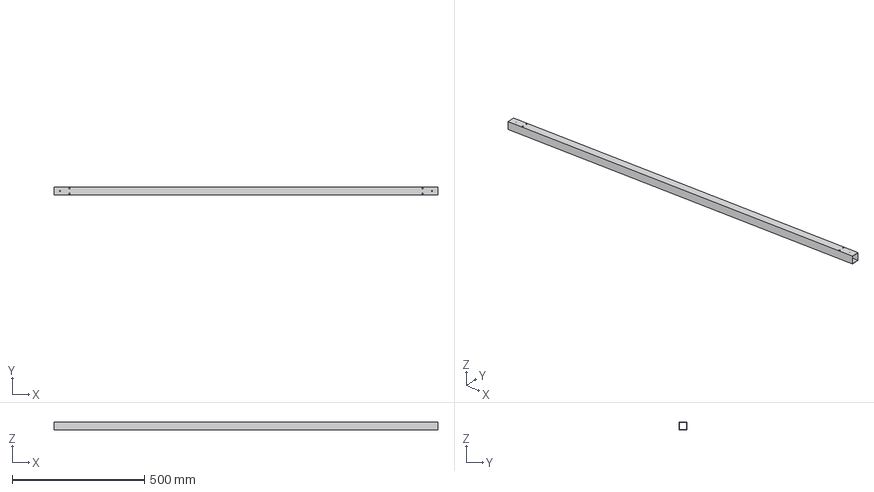
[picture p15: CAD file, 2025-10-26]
CAD/aluminum_pipe/stacking_horizontal_spreader.step
1450.0 x 30.0 x 30.0 mm

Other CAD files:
CAD/3d_print/feed_box/feed_box_front.step
CAD/aluminum_pipe/yagi_boom_middle.step
CAD/aluminum_pipe/yagi_boom_front.step
CAD/aluminum_pipe/yagi_boom_rear.step

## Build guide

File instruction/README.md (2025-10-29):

# Antenna Fabrication and Assembly Guide

## 1. Introduction

This document provides a step-by-step guide for fabricating and assembling all components for the Portable 432MHz EME Yagi Array.

**Critical Note:** Please follow these steps in the specified order. Some steps (like 3D printing) are required to create tools (jigs) needed for later steps (like aluminum machining).

For a complete Bill of Materials (BOM), please refer to the main [README.md](/README.md) file.

---

## 2. Required Tools

Before starting, ensure you have the following basic tools:

* 3D Printer
* Hand drill (pistol drill) or drill press
* Hand saw (for aluminum)
* Manual rivet gun
* Soldering iron (for installing heat-set inserts)
* Hex key (Allen wrench) set (M3)
* Wire stripper / Coax cable cutter
* Crimping tool (for RNB-1.25-4 lugs)
* Vector Network Analyzer (VNA) (Highly Recommended for verifying coax length)
* Permanent marker

---

## 3. Part 1: Component Fabrication

This section covers the creation of all custom parts from raw materials.

### Step 3.1: 3D Printing

This is the **first** fabrication step. The 3D-printed parts, especially the drilling jigs, are required for the aluminum machining.

1.  Navigate to the `/CAD/3d_print/` directory.
2.  Read the general printing guidelines in the main `README.md`.
3.  **Crucially**, read the specific `README.md` file *inside each subdirectory* (e.g., `feed_box/`, `element_mount/`, `drilling_jig/`) before printing. These files contain essential instructions on print orientation, supports, and required hardware.
4.  Print all required parts, paying special attention to the parts in the `drilling_jig/` directory, which are needed for Step 3.2.

> **IMPORTANT:** Failure to print the `drilling_jig` parts first will make accurate manual machining of the aluminum tubes extremely difficult.

### Step 3.2: Aluminum Machining

This step involves cutting and drilling all aluminum components for the elements, booms, and H-frame.

#### 3.2.1. Yagi Elements (Reflector & Directors)

Cut the parasitic elements (8mm diameter tubes) to their **full "Final BC Length"** specified in the table below. The "Drilling Midpoint" column indicates the **midpoint (center) of the element**, which is where you must drill the mounting hole.

Use the `element_drill_jig.step` (from the `../3d_print/drilling_jig/` directory) to ensure the hole is drilled precisely at the center. You will need to make 4 identical sets.

| Element | Qty (per Yagi) | Diam (mm) | **Cut Full Length (mm)** (Final BC Length) | **Drilling Midpoint (mm)** (Half L) |
|:---|:---|:---|:---|:---|
| Refl | 1 | 8 | 330.7 | 165.35 |
| D1 | 1 | 8 | 311.7 | 155.85 |
| D2 | 1 | 8 | 306.7 | 153.35 |
| D3 | 1 | 8 | 294.7 | 147.35 |
| D4 | 1 | 8 | 288.7 | 144.35 |
| D5 | 1 | 8 | 284.7 | 142.35 |
| D6 | 1 | 8 | 281.7 | 140.85 |
| D7 | 1 | 8 | 277.2 | 138.6 |
| D8 | 1 | 8 | 273.7 | 136.85 |
| D9 | 1 | 8 | 270.7 | 135.35 |
| D10 | 1 | 8 | 268.7 | 134.35 |
| D11 | 1 | 8 | 266.7 | 133.35 |
| D12 | 1 | 8 | 258.7 | 129.35 |

*Note: The Driven Element (DE) is a 10mm tube and is prepared as part of the Feed Box assembly (Part 5.1).*

#### 3.2.2. Yagi Booms & H-Frame

Machine the aluminum square tubes for the Yagi booms and the H-frame according to the `.step` files in the `/CAD/aluminum_pipe/` directory.

**Manufacturing Recommendations:**
* **Manual (DIY):** Cut parts with a hand saw and use a drill press. It is **ESSENTIAL** to use the 3D-printed jigs from the `/CAD/3d_print/drilling_jig/` directory (e.g., `hinge_drill_jig.step`, `mast_drill_jig.step`) for all hinge and alignment holes.
* **Professional (CNC):** The `.step` files are CAM-ready and can be sent directly to a machining service for laser cutting or CNC milling.

**Machining Summary:**

| Module | Part File(s) | Material | Qty | Key Machining Notes |
|:---|:---|:---|:---|:---|
| **Yagi Booms** | `yagi_boom_front.step`<br>`yagi_boom_middle.step`<br>`yagi_boom_rear.step` | 20x20x1mm Square Tube | 4 of each<br>(12 total) | • Cut to length as per STEP file.<br>• Drill element holes.<br>• **Critical:** Use `hinge_drill_jig.step` for all hinge/latch holes at the ends. |
| **H-Frame** | `stacking_vertical_mast.step` | 25x25x1mm Square Tube | 4 | • Forms the two vertical legs.<br>• **Critical:** Use `mast_drill_jig.step` for hinge holes. |
| **H-Frame** | `stacking_horizontal_spreader.step` | 30x30x1mm Square Tube | 1 | • The central horizontal spine.<br>• **Critical:** Use `spreader_drill_jig.step` for hinge holes. |
| **Adapters** | `boom_sleeve.step` | 25x25x2.5mm Square Tube | 8 | • Adapts 20mm boom to 25mm T-connector.<br>• **Manufacture:** Cut tube in half *lengthwise*. Low precision required. |

---

## 4. Part 2: Component Preparation

This section covers the preparation of off-the-shelf components before final assembly.

### Step 4.1: Coaxial Feedlines

Each of the four Yagis requires a 3/4 wavelength ($3/4 \lambda$) coaxial feedline (balun).

1.  **Verify Velocity Factor (VF):** The VF for SVY-50-3 coax is approximately **0.66**. For best results, use a VNA to measure the precise VF of your specific coax cable.
2.  **Calculate Length:** The formula is: $(\text{Wavelength} \times 0.75) \times \text{VF}$.
    * Example calculation: $(69.4 \text{ cm} \times 0.75) \times 0.66 = \mathbf{34.353 \text{ cm}}$
3.  **Cut Cables:** Cut **4** identical lengths of SVY-50-3 coax based on your calculation.
4.  **Prepare Ends (One Side):** On *one end* of each of the 4 cables:
    * Strip back ~1.5 cm of the outer jacket to expose the shield.
    * Carefully push the braided shield back, exposing the inner dielectric.
    * Strip back ~0.5 - 1 cm of the dielectric to expose the center core.
    * Twist the braided shield neatly into a single "pigtail."
5.  **Crimp Lugs:**
    * Crimp one **RNB-1.25-4** copper lug onto the center core.
    * Crimp one **RNB-1.25-4** copper lug onto the twisted shield pigtail.
    * You now have 4 coax cables, each with one end terminated in two lugs.

---

## 5. Part 3: Sub-Assembly

This section covers the assembly of the main modules.

### Step 5.1: Feed Box & Driven Element Assembly

This is a critical step that requires careful attention to detail. You will be building **two pairs** of mirrored feed boxes.

> **CRITICAL WARNING: Symmetrical Assembly Required**
>
> Because two Yagis mount "right-side up" and two mount "upside down" on the H-frame, you **MUST** build two "standard" feed boxes and two "mirrored" (symmetrical) feed boxes.
>
> If all four feed boxes are identical, two antennas will be 180° out of phase, and the array will **NOT** work.

To be clear, you must build two of each configuration shown below:

| Assembly Type | Quantity to Build | Wiring Configuration |
|:---|:---|:---|
| **"Standard" (L)** | 2 | **Center Core** $\rightarrow$ **Left** DE Half<br>**Shield** $\rightarrow$ **Right** DE Half |
| **"Mirrored" (R)** | 2 | **Center Core** $\rightarrow$ **Right** DE Half<br>**Shield** $\rightarrow$ **Left** DE Half |

#### Assembly Process:

1.  **Install Heat-Set Inserts:** Using a soldering iron, melt **M3x4x5** brass inserts into:
    * The bottom and both sides of the T-shaped `feed_box_middle` part.
    * The corresponding holes in the `feed_box_front` and `feed_box_rear` covers.
2.  **Install Center Bolt:**
    * Take one **M3x40** socket head cap screw.
    * Screw it down *from the top* of the T-part (`feed_box_middle`).
    * Thread it *through* the heat-set insert at the bottom of the T-part.
    * Tighten this screw firmly. It should be locked in place by the insert and not rotate.
3.  **Install Driven Element (DE):**
    * Insert the bent 10mm diameter aluminum tube (the Driven Element) into the T-part.
    * **CRITICAL ALIGNMENT:** Rotate the DE so that the *direction of its bend* is the *same* as the direction of the heat-set inserts on the sides of the T-part.
4.  **Connect Feedline:**
    * Take one of the prepared coax cables from Step 4.1.
    * Use two **M3x8** button head screws.
    * Feed the screws from the *opposite side* of the side-inserts (i.e., from the "inside" of the T-part).
    * Pass the screws through the holes in the Driven Element.
    * Attach the two crimped lugs (Core and Shield) to the screws.
5.  **FINAL CHECK (Standard vs. Mirrored):**
    * **For 2 assemblies:** Attach the **Center Core** lug to the **Left** DE half and the **Shield** lug to the **Right** DE half.
    * **For the other 2 assemblies:** Attach the **Center Core** lug to the **Right** DE half and the **Shield** lug to the **Left** DE half.
6.  **Mark Assemblies:** Use a permanent marker to clearly label the "Standard" and "Mirrored" assemblies (e.g., "L" and "R") so you do not mix them up during final assembly.

---

*(Tutorial sections below will be added based on future information)*

### Step 5.2: Yagi Boom Assembly (Hinges & Mounts)

*(Instructions for attaching hinges, latches, and 3D-printed caps to the boom sections to be added here.)*

### Step 5.3: Parasitic Element Installation

*(Instructions for attaching the 52 `element_mount` parts and the elements to the booms to be added here.)*

---

## 6. Part 4: Final Assembly

### Step 6.1: H-Frame Assembly

*(Instructions for assembling the vertical and horizontal H-frame parts with the 90-degree folding hinges to be added here.)*

### Step 6.2: Mounting Yagis to H-Frame

*(Instructions for mounting the four Yagi assemblies to the H-frame quick-release connectors to be added here.)*

### Step 6.3: Connecting Phasing Lines

*(Instructions for connecting the four feed boxes to the power divider/phasing harness to be added here.)*

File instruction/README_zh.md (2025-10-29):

# 天线加工与装配指南

## 1. 简介

本文档提供了便携式 432MHz EME 八木天线阵列所有组件的详细加工和装配步骤。

**重要提示：** 请严格按照本文档指定的顺序执行。某些步骤（如3D打印）是后续步骤（如铝管加工）所需工具（钻孔工装）的前提。

完整的物料清单 (BOM)，请参阅项目主 [README.md](/README.md) 文件。

---

## 2. 所需工具

在开始之前，请确保您拥有以下基本工具：

* 3D 打印机
* 手电钻或台钻
* 手锯（用于切割铝材）
* 手动拉铆枪
* 电烙铁（用于安装热熔螺母）
* M3 内六角扳手
* 剥线钳 / 同轴电缆剪
* 压线钳（用于 RNB-1.25-4 端子）
* 矢量网络分析仪 (VNA)（强烈推荐，用于精确测量馈线）
* 记号笔

---

## 3. 第一部分：零件加工

本节涵盖了所有定制零件的从零开始的制造过程。

### 步骤 3.1：3D打印

这是加工的**第一步**。3D打印的零件，特别是钻孔工装（drilling jigs），是后续铝管加工所必需的。

1.  进入 `/CAD/3d_print/` 目录。
2.  阅读主 `README.md` 文件中的通用打印建议。
3.  **关键：** 在打印前，请务必阅读**每个子目录中**特定的 `README.md` 文件（例如 `feed_box/`、`element_mount/`、`drilling_jig/`）。这些文件包含了关于打印方向、支撑和所需五金件的重要说明。
4.  打印所有需要的零件，特别注意 `drilling_jig/` 目录中的零件，它们是步骤 3.2 所必需的。

> **重要提示：** 如果不首先打印 `drilling_jig` 零件，后续对铝管的精确手动钻孔将变得极其困难。

### 步骤 3.2：铝管加工

此步骤包括切割和钻孔构成振子、主梁和H型框架的所有铝制部件。

#### 3.2.1. 八木天线振子 (反射器 & 引导器)

根据下表，将 8mm 直径的铝管切割成**完整的“最终 BC 长度”**。表中的“钻孔中点”列实际上是指振子的**中点位置（半长）**，您必须在此位置钻安装孔。

请使用 `../3d_print/drilling_jig/` 目录中的 `element_drill_jig.step` 工装来确保钻孔位置精确位于中心。您需要制作4套完全相同的振子。

| 振子 | 数量 (每根八木) | 直径 (mm) | **切割全长 (mm)** (最终 BC 长度) | **钻孔中点 (mm)** (半长) |
|:---|:---|:---|:---|:---|
| Refl (反射器) | 1 | 8 | 330.7 | 165.35 |
| D1 | 1 | 8 | 311.7 | 155.85 |
| D2 | 1 | 8 | 306.7 | 153.35 |
| D3 | 1 | 8 | 294.7 | 147.35 |
| D4 | 1 | 8 | 288.7 | 144.35 |
| D5 | 1 | 8 | 284.7 | 142.35 |
| D6 | 1 | 8 | 281.7 | 140.85 |
| D7 | 1 | 8 | 277.2 | 138.6 |
| D8 | 1 | 8 | 273.7 | 136.85 |
| D9 | 1 | 8 | 270.7 | 135.35 |
| D10 | 1 | 8 | 268.7 | 134.35 |
| D11 | 1 | 8 | 266.7 | 133.35 |
| D12 | 1 | 8 | 258.7 | 129.35 |

*注意：激励振子 (DE) 是 10mm 铝管，它将在馈电盒装配（第 5.1 部分）中单独准备。*

#### 3.2.2. 八木主梁 (Booms) & H型框架 (H-Frame)

根据 `/CAD/aluminum_pipe/` 目录中的 `.step` 文件，加工用于八木主梁和H型框架的铝方管。

**加工建议:**
* **手动 (DIY):** 使用手锯切割，并使用台钻钻孔。**至关重要：** 必须使用 `/CAD/3d_print/drilling_jig/` 目录中 3D 打印的工装（如 `hinge_drill_jig.step`, `mast_drill_jig.step` 等）来钻所有铰链和对齐孔。
* **专业 (CNC):** `.step` 文件是 CAM 就绪的，可直接发送给加工服务商进行激光切割或 CNC 铣削。

**加工概要:**

| 模块 | 零件文件 | 材料 | 数量 | 关键加工说明 |
|:---|:---|:---|:---|:---|
| **八木主梁** | `yagi_boom_front.step`<br>`yagi_boom_middle.step`<br>`yagi_boom_rear.step` | 20x20x1mm 方管 | 每种 4 个<br>(共 12 个) | • 按 STEP 文件切割长度。<br>• 钻振子孔。<br>• **关键:** 在末端使用 `hinge_drill_jig.step` 钻所有铰链/锁扣孔。 |
| **H型框架** | `stacking_vertical_mast.step` | 25x25x1mm 方管 | 4 | • 构成两条垂直 "腿"。<br>• **关键:** 使用 `mast_drill_jig.step` 钻铰链孔。 |
| **H型框架** | `stacking_horizontal_spreader.step` | 30x30x1mm 方管 | 1 | • 中央水平脊柱。<br>• **关键:** 使用 `spreader_drill_jig.step` 钻铰链孔。 |
| **适配器**  | `boom_sleeve.step` | 25x25x2.5mm 方管 | 8 | • 用于将 20mm 主梁适配到 25mm T型接头。<br>• **制造:** 沿长度方向将管子切成两半。精度要求不高。 |

---

## 4. 第二部分：组件准备

本节涵盖了在最终组装前对标准组件的预处理。

### 步骤 4.1：同轴馈线

每根八木天线都需要一条 3/4 波长 ($3/4 \lambda$) 的同轴馈线（兼作巴伦）。

1.  **确认速度系数 (VF):** SVY-50-3 同轴电缆的速度系数 (VF) 约为 **0.66**。为获得最佳效果，请使用 VNA 测量您手中电缆的精确 VF。
2.  **计算长度:** 公式为： $(\text{波长} \times 0.75) \times \text{VF}$。
    * 示例计算: $(69.4 \text{ cm} \times 0.75) \times 0.66 = \mathbf{34.353 \text{ cm}}$
3.  **裁剪电缆:** 根据您的计算，裁剪 **4** 根长度完全相同的 SVY-50-3 电缆。
4.  **处理末端 (一侧):** 在每根电缆的*一端*进行如下处理：
    * 剥去约 1.5 cm 的外护套，露出屏蔽层。
    * 小心地将编织屏蔽网向后推，露出内部介电层。
    * 剥去约 0.5 - 1 cm 的介电层，露出中心芯线。
    * 将编织屏蔽网整齐地捻成一股。
5.  **压接端子:**
    * 将一个 **RNB-1.25-4** 铜鼻子压接到中心芯线上。
    * 将一个 **RNB-1.25-4** 铜鼻子压接到捻成一股的屏蔽网上。
    * 现在您应有4根馈线，每根的一端都已端接好两个压线端子。

---

## 5. 第三部分：子组件装配

本节涵盖了主要模块的组装。

### 步骤 5.1：馈电盒与激励振子装配

这是关键一步，需要格外小心。您将需要制作**两对**镜像对称的馈电盒。

> **严重警告：必须对称装配**
>
> 由于两根八木天线 "正向" 安装在H架上，另外两根 "反向" (上下颠倒) 安装，您**必须**制作两个 "标准" 馈电盒和两个 "镜像" (对称) 馈电盒。
>
> 如果所有四个馈电盒都完全相同，将导致两根天线的相位相差 180°，阵列将**无法工作**。

为清晰起见，您必须按下表所示，每种配置各制作两个：

| 装配类型 | 制作数量 | 接线配置 |
|:---|:-----|:---|
| **"标准" (L)** | 2 | **芯线** $\rightarrow$ **左侧**激励振子<br>**屏蔽层** $\rightarrow$ **右侧**激励振子 |
| **"镜像" (R)** | 2 | **芯线** $\rightarrow$ **右侧**激励振子<br>**屏蔽层** $\rightarrow$ **左侧**激励振子 |

#### 装配流程:

1.  **安装热熔螺母:** 使用电烙铁，将 **M3x4x5** 铜螺母热熔进：
    * T 形零件 `feed_box_middle` 的底部和两侧沉孔。
    * `feed_box_front` (前盖) 和 `feed_box_rear` (后盖) 上的对应沉孔。
2.  **安装中心螺栓:**
    * 取一根 **M3x40** 杯头内六角螺栓。
    * 从 T 形零件 (`feed_box_middle`) 的顶部旋入。
    * 使其穿过 T 形零件底部的热熔螺母。
    * 拧紧这根螺栓。它应该被底部的螺母锁死，无法转动或松动。
3.  **安装激励振子 (DE):**
    * 将折弯好的 10mm 直径铝管（激励振子）插入 T 形零件中。
    * **关键对齐：** 旋转激励振子，使其*弯曲的方向*与 T 形零件两侧热熔螺母的*方向保持一致*。
4.  **连接馈线:**
    * 取一根步骤 4.1 中准备好的同轴馈线。
    * 使用两颗 **M3x8** 圆头内六角螺栓。
    * 将螺栓从侧面螺母的*反侧*（即 T 形零件的“内部”）穿入。
    * 使螺栓穿过激励振子上的孔。
    * 将两个压接端子（芯线和屏蔽层）分别固定在螺栓上。
5.  **最终检查 (标准 vs 镜像):**
    * **对于 2 个组件：** 将**芯线**端子连接到**左侧**激励振子，**屏蔽层**端子连接到**右侧**。
    * **对于另外 2 个组件：** 将**芯线**端子连接到**右侧**激励振子，**屏蔽层**端子连接到**左侧**。
6.  **标记组件:** 使用记号笔在 "标准" 和 "镜像" 组件上做好清晰标记（例如 "L" 和 "R"），以免在总装时混淆。

---

*(以下教程部分将根据未来的信息补充)*

### 步骤 5.2：八木主梁装配 (铰链与锁扣)

*(此处将添加关于将铰链、锁扣和3D打印端盖安装到主梁各分段的说明。)*

### 步骤 5.3：无源振子安装

*(此处将添加关于将 52 个 `element_mount` 部件和振子安装到主梁上的说明。)*

---

## 6. 第四部分：最终总装

### 步骤 6.1：H型框架装配

*(此处将添加关于使用90度折叠铰链组装H型框架垂直立柱和水平横梁的说明。)*

### 
步骤 6.2：安装八木天线至H型框架

*(此处将添加关于将四套八木天线组件安装到H型框架快速释放连接件上的说明。)*

### 步骤 6.3：连接相位线

*(此处将添加关于将四个馈电盒连接到功分器/相位匹配网络的说明。)*

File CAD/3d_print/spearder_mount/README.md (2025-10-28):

# Printing Instructions

[English](#english) | [中文 (Chinese)](#中文-chinese) | [Deutsche (German)](#deutsche-german) | [日本語 (Japanese)](#日本語-japanese)

---

## English

### Parts
* `spearder_mount_lower.step`
* `spearder_mount_upper.step`

### Purpose
These parts connect the entire antenna array (H-frame) to a tripod's quick-release (QR) plate.

### ⚠️ Critical Note
These are critical load-bearing components that support the entire array. They will be under **very high stress** during use. It is **strongly recommended** to print these parts at or above the following specifications to prevent failure.

### Recommended Print Settings
(These settings apply to both parts)

| Parameter | Value |
|:---|:---|
| **Material** | PETG |
| **Nozzle Diameter** | 0.4mm |
| **Layer Height** | 0.2mm |
| **Wall Thickness**  | 6 Layers |
| **Top Layers** | 5 Layers |
| **Bottom Layers** | 5 Layers |
| **Infill Density**  | 30% |
| **Infill Pattern**  | Cross Hatch |

### Orientation & Supports
* **Orientation:** Place the large rectangular flat side down on the print bed. The "V-shaped" groove should face upwards.
* **Supports:** **Must be enabled.**

---

## 中文 (Chinese)

### 零件
* `spearder_mount_lower.step`
* `spearder_mount_upper.step`

### 用途
这些零件用于将整个天线阵列 (H-Frame) 固定到三脚架的快装板 (QR Plate) 上。

### ⚠️ 重要提示
这些是关键的承力部件，用于支撑整个天线阵列，在使用中会承受**非常大的力**。为了防止失效，**强烈建议**使用以下推荐参数或更高规格进行打印。

### 推荐打印参数
(以下参数适用于两个零件)

| 参数 | 数值 |
|:---|:---|
| **材料** | PETG |
| **喷嘴直径** | 0.4mm |
| **层高** | 0.2mm |
| **壁厚** | 6 层 |
| **顶部层数** | 5 层 |
| **底部层数** | 5 层 |
| **填充密度** | 30% |
| **填充图案** | 交叉层叠 (Cross Hatch) |

### 打印方向与支撑
* **打印方向:** 将大的长方形平面朝下放置在打印床上，V 字凹槽朝上。
* **支撑:** **必须启用支撑。**

---

## Deutsche (German)

### Bauteile
* `spearder_mount_lower.step`
* `spearder_mount_upper.step`

### Zweck
Diese Teile verbinden die gesamte Antennenanordnung (H-Rahmen) mit der Schnellwechselplatte (QR-Platte) eines Stativs.

### ⚠️ Wichtiger Hinweis
Dies sind kritische, tragende Komponenten, die die gesamte Anordnung halten. Sie stehen während des Gebrauchs unter **sehr hoher Belastung**. Es wird **dringend empfohlen**, diese Teile mit den folgenden oder höheren Spezifikationen zu drucken, um ein Versagen zu verhindern.

### Empfohlene Druckeinstellungen
(Diese Einstellungen gelten für beide Bauteile)

| Parameter | Wert |
|:---|:---|
| **Material** | PETG |
| **Düsendurchmesser** | 0.4mm |
| **Schichthöhe** | 0.2mm |
| **Wandstärke** | 6 Schichten |
| **Obere Schichten**  | 5 Schichten |
| **Untere Schichten** | 5 Schichten |
| **Fülldichte** | 30% |
| **Füllmuster** | Cross Hatch |

### Ausrichtung & Stützstrukturen
* **Ausrichtung:** Legen Sie die große, rechteckige flache Seite nach unten auf das Druckbett. Die "V-förmige" Nut sollte nach oben zeigen.
* **Stützstrukturen:** **Müssen aktiviert sein.**

---

## 日本語 (Japanese)

### パーツ
* `spearder_mount_lower.step`
* `spearder_mount_upper.step`

### 目的
これらのパーツは、アンテナアレイ全体（Hフレーム）を三脚のクイックリリース（QR）プレートに接続するために使用されます。

### ⚠️ 重要事項
これらはアレイ全体を支える重要な耐荷重部品です。使用時には**非常に高い応力**がかかります。破損を防ぐため、これらのパーツは以下の推奨仕様またはそれ以上で印刷することを**強く推奨します**。

### 推奨印刷設定
（これらの設定は両方のパーツに適用されます）

| パラメータ | 値 |
|:---|:---|
| **素材** | PETG |
| **ノズル径** | 0.4mm |
| **積層ピッチ**  | 0.2mm |
| **壁の厚さ** | 6 層 |
| **上部レイヤー** | 5 層 |
| **底部レイヤー** | 5 層 |
| **充填密度** | 30% |
| **充填パターン** | クロスハッチ (Cross Hatch) |

### 配置とサポート
* **配置:** 大きな長方形の平らな面をプリントベッド側（下）に向け、「V字型」の溝が上を向くように配置してください。
* **サポート:** **有効にする必要があります。**

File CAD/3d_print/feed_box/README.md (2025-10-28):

# Printing Instructions

[English](#english) | [中文 (Chinese)](#中文-chinese) | [Deutsche (German)](#deutsche-german) | [日本語 (Japanese)](#日本語-japanese)

---

## English

### Parts
* `feed_box_front.step`
* `feed_box_middle.step`
* `feed_box_rear.step`
* `feed_box_isolator.step`

### Purpose
These parts assemble into a weatherproof box for the antenna's feed point. This box protects the feed point, secures the driven element, and holds the feedline connector (e.g., N-type connector). It consists of three shell components and one T-shaped isolator.

### Note
These parts are under moderate stress. The following general-purpose mechanical part settings are recommended.

### Recommended General Print Settings
The following settings apply to **all four parts** in this directory. Part-specific instructions for orientation and supports are listed below.

| Parameter | Value |
|:---|:---|
| **Material** | PETG |
| **Nozzle Diameter** | 0.4mm |
| **Layer Height** | 0.2mm |
| **Wall Thickness**  | 4 Layers |
| **Top Layers** | 4 Layers |
| **Bottom Layers** | 4 Layers |
| **Infill Density**  | 25% |
| **Infill Pattern**  | Cross Hatch |

---

### Part-Specific Instructions

#### 1. `feed_box_front`
* **Orientation:** Place the large flat face down on the print bed. The square opening should face upwards.
* **Supports:** **Manual (Custom) Supports Required.**
    * **Enable supports** *only* for the three countersunk "steps" (which are for the heat-set brass nuts).
    * **Disable supports** for all other areas. Note that the small groove (for the N-connector's waterproof O-ring) also **does not require support**.

#### 2. `feed_box_middle`
* **Orientation:** Place the large flat face down on the print bed. The semi-cylindrical groove should face upwards.
* **Supports:** **Must be enabled.**

#### 3. `feed_box_rear`
* **Orientation:** Place the large flat face down on the print bed. The semi-cylindrical groove should face upwards.
* **Supports:** **Must be enabled.**

#### 4. `feed_box_isolator`
* **Orientation:** Lay the part flat on the bed (in its "T" shape).
* **Supports:** **Not required.**

---
---

## 中文 (Chinese)

### 零件
* `feed_box_front.step`
* `feed_box_middle.step`
* `feed_box_rear.step`
* `feed_box_isolator.step`

### 用途
这些零件用于组装成一个馈电点防水盒。它用于保护馈电点、固定激励振子，并固定馈线连接座 (例如 N 型连接器)。它由三个外壳零件和一个 T 字形的绝缘零件组成。

### 注意
这些零件承受中等强度的受力，建议使用以下通用的机械零件参数进行打印。

### 推荐的通用打印参数
以下参数适用于此文件夹中的**所有四个零件**。每个零件特定的打印方向和支撑设置请见下方。

| 参数 | 数值 |
|:---|:---|
| **材料** | PETG |
| **喷嘴直径** | 0.4mm |
| **层高** | 0.2mm |
| **壁厚** | 4 层 |
| **顶部层数** | 4 层 |
| **底部层数** | 4 层 |
| **填充密度** | 25% |
| **填充图案** | 交叉层叠 (Cross Hatch) |

---

### 零件专属设置

#### 1. `feed_box_front`
* **打印方向:** 将大平面朝下放置在打印床上，方形槽口朝上。
* **支撑:** **需要手动绘制支撑 (Custom Supports)**。
    * **仅**为 3 个用于嵌入铜螺母的沉孔台阶**启用支撑**。
    * 在所有其他位置**禁用支撑**。请注意，用于安装 N 型连接器 (N-type connector) 防水O形圈的凹槽也**无须支撑**。

#### 2. `feed_box_middle`
* **打印方向:** 将大平面朝下放置在打印床上，半圆柱凹槽朝上。
* **支撑:** **必须启用支撑**。

#### 3. `feed_box_rear`
* **打印方向:** 将大平面朝下放置在打印床上，半圆柱凹槽朝上。
* **支撑:** **必须启用支撑**。

#### 4. `feed_box_isolator`
* **打印方向:** 将零件 T 字形平放在打印床上。
* **支撑:** **无须开启支撑。**

---
---

## Deutsche (German)

### Bauteile
* `feed_box_front.step`
* `feed_box_middle.step`
* `feed_box_rear.step`
* `feed_box_isolator.step`

### Zweck
Diese Teile werden zu einer wetterfesten Box für den Speisepunkt der Antenne zusammengebaut. Diese Box schützt den Speisepunkt, fixiert das Erregerelement und hält den Speiseleitungsanschluss (z. B. N-Buchse). Sie besteht aus drei Gehäusekomponenten und einem T-förmigen Isolator.

### Hinweis
Diese Teile sind einer mäßigen Belastung ausgesetzt. Die folgenden Einstellungen für mechanische Standardbauteile werden empfohlen.

### Empfohlene Allgemeine Druckeinstellungen
Die folgenden Einstellungen gelten für **alle vier Bauteile** in diesem Verzeichnis. Teilespezifische Anweisungen zur Ausrichtung und zu Stützstrukturen sind unten aufgeführt.

| Parameter | Wert |
|:---|:---|
| **Material** | PETG |
| **Düsendurchmesser** | 0.4mm |
| **Schichthöhe** | 0.2mm |
| **Wandstärke** | 4 Schichten |
| **Obere Schichten**  | 4 Schichten |
| **Untere Schichten** | 4 Schichten |
| **Fülldichte** | 25% |
| **Füllmuster** | Cross Hatch |

---

### Teilespezifische Anweisungen

#### 1. `feed_box_front`
* **Ausrichtung:** Legen Sie die große, flache Seite nach unten auf das Druckbett. Die quadratische Öffnung sollte nach oben zeigen.
* **Stützstrukturen:** **Manuelle (benutzerdefinierte) Stützstrukturen erforderlich.**
    * Stützstrukturen **nur** für die drei Senkungen (Stufen) **aktivieren**, die für die Messing-Gewindeeinsätze vorgesehen sind.
    * Stützstrukturen für alle anderen Bereiche **deaktivieren**. Beachten Sie, dass die kleine Nut (für den wasserdichten O-Ring des N-Steckers) ebenfalls **keine Stützstruktur benötigt**.

#### 2. `feed_box_middle`
* **Ausrichtung:** Legen Sie die große, flache Seite nach unten auf das Druckbett. Die halbzylindrische Nut sollte nach oben zeigen.
* **Stützstrukturen:** **Müssen aktiviert sein.**

#### 3. `feed_box_rear`
* **Ausrichtung:** Legen Sie die große, flache Seite nach unten auf das Druckbett. Die halbzylindrische Nut sollte nach oben zeigen.
* **Stützstrukturen:** **Müssen aktiviert sein.**

#### 4. `feed_box_isolator`
* **Ausrichtung:** Legen Sie das Teil flach (in seiner "T"-Form) auf das Druckbett.
* **Stützstrukturen:** **Nicht erforderlich.**

---
---

## 日本語 (Japanese)

### パーツ
* `feed_box_front.step`
* `feed_box_middle.step`
* `feed_box_rear.step`
* `feed_box_isolator.step`

### 目的
これらのパーツは、アンテナの給電点用の耐候性ボックス（防水箱）を構成します。このボックスは給電点を保護し、給電素子を固定し、給電コネクタ（N型コネクタなど）を保持します。3つのシェルパーツと1つのT字型絶縁パーツで構成されています。

### 注意
これらのパーツには中程度の負荷がかかります。以下の一般的な機械部品用の設定で印刷することを推奨します。

### 推奨共通印刷設定
以下の設定は、このディレクトリ内の**4つのパーツすべて**に適用されます。パーツごとの配置とサポートに関する指示は、下記を参照してください。

| パラメータ | 値 |
|:---|:---|
| **素材** | PETG |
| **ノズル径** | 0.4mm |
| **積層ピッチ**  | 0.2mm |
| **壁の厚さ** | 4 層 |
| **上部レイヤー** | 4 層 |
| **底部レイヤー** | 4 層 |
| **充填密度** | 25% |
| **充填パターン** | クロスハッチ (Cross Hatch) |

---

### パーツ別設定

#### 1. `feed_box_front`
* **配置:** 大きな平らな面をプリントベッド側（下）に向け、四角い開口部が上を向くように配置します。
* **サポート:** **手動（カスタム）サポートが必要**です。
    * 熱圧入ナット用の3つの皿穴（段差部分）**にのみサポートを有効**にしてください。
    * 他のすべての領域ではサポートを**無効**にしてください。なお、N型コネクタの防水Oリング用の小さな溝も**サポート不要**です。

#### 2. `feed_box_middle`
* **配置:** 大きな平らな面をプリントベッド側（下）に向け、半円筒形の溝が上を向くように配置します。
* **サポート:** **有効にする必要があります。**

#### 3. `feed_box_rear`
* **配置:** 大きな平らな面をプリントベッド側（下）に向け、半円筒形の溝が上を向くように配置します。
* **サポート:** **有効にする必要があります。**

#### 4. `feed_box_isolator`
* **配置:** パーツを「T」の字になるように平らにプリントベッドに配置します。
* **サポート:** **不要です。**

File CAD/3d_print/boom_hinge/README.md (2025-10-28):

# Printing Instructions

[English](#english) | [中文 (Chinese)](#中文-chinese) | [Deutsche (German)](#deutsche-german) | [日本語 (Japanese)](#日本語-japanese)

---

## English

### Parts
* `boom_hinge_cap_front.step`
* `boom_hinge_cap_rear.step`

### Purpose
These parts are installed at the Yagi boom's folding hinge. They serve to align the boom segments and fill the gap at the pivot.

### ⚠️ Critical Note
These components are under **significant pressure** during assembly and use. It is **strongly recommended** to print them with thick walls as specified below. Insufficient wall thickness will cause the parts to crack and become lodged inside the boom, making them impossible to remove.

### Recommended Print Settings

| Parameter | Value |
|:---|:---|
| **Material** | PETG |
| **Nozzle Diameter** | 0.4mm |
| **Layer Height** | 0.2mm |
| **Wall Thickness**  | 5 Layers |
| **Top Layers** | 6 Layers |
| **Bottom Layers** | 5 Layers |
| **Infill Density**  | 40% |
| **Infill Pattern**  | Cross Hatch |

### Orientation & Supports
* **Orientation:** Place the large flat side down on the print bed. The concave and convex features should face upwards.
* **Supports:** **Supports must be enabled.**

---

## 中文 (Chinese)

### 零件
* `boom_hinge_cap_front.step`
* `boom_hinge_cap_rear.step`

### 用途
这两个零件用于安装在八木 (Yagi) 主梁的折叠处。它们用于对齐主梁位置，并填补转轴处的隙间。

### ⚠️ 重要提示
这些零件在安装和使用中会承受**较大的压力**。**强烈建议**使用以下指定的厚壁参数来打印它们。如果壁厚不足，会导致零件在安装时破裂并卡在主梁内部，从而无法取出。

### 推荐打印参数

| 参数 | 数值 |
|:---|:---|
| **材料** | PETG |
| **喷嘴直径** | 0.4mm |
| **层高** | 0.2mm |
| **壁厚** | 5 层 |
| **顶部层数** | 6 层 |
| **底部层数** | 5 层 |
| **填充密度** | 40% |
| **填充图案** | 交叉层叠 (Cross Hatch) |

### 打印方向与支撑
* **打印方向:** 将零件的大平面朝下放置在打印床上，凹面和凸面朝上。
* **支撑:** **必须启用支撑。**

---

## Deutsche (German)

### Bauteile
* `boom_hinge_cap_front.step`
* `boom_hinge_cap_rear.step`

### Zweck
Diese Teile werden am Klappscharnier des Yagi-Booms (Mastträgers) installiert. Sie dienen dazu, die Boom-Segmente auszurichten und den Spalt am Gelenk zu füllen.

### ⚠️ Wichtiger Hinweis
Diese Komponenten stehen bei der Montage und im Gebrauch unter **erheblichem Druck**. Es **wird dringend empfohlen**, sie mit dicken Wänden gemäß den folgenden Angaben zu drucken. Eine unzureichende Wandstärke führt dazu, dass die Teile reißen und im Inneren des Booms stecken bleiben, was ein Entfernen unmöglich macht.

### Empfohlene Druckeinstellungen

| Parameter | Wert |
|:---|:---|
| **Material** | PETG |
| **Düsendurchmesser** | 0.4mm |
| **Schichthöhe** | 0.2mm |
| **Wandstärke** | 5 Schichten |
| **Obere Schichten**  | 6 Schichten |
| **Untere Schichten** | 5 Schichten |
| **Fülldichte** | 40% |
| **Füllmuster** | Cross Hatch |

### Ausrichtung & Stützstrukturen
* **Ausrichtung:** Legen Sie die große, flache Seite nach unten auf das Druckbett. Die konkaven und konvexen Merkmale sollten nach oben zeigen.
* **Stützstrukturen:** **Stützstrukturen müssen aktiviert sein.**

---

## 日本語 (Japanese)

### パーツ
* `boom_hinge_cap_front.step`
* `boom_hinge_cap_rear.step`

### 目的
これらのパーツは、八木アンテナのブームの折りたたみヒンジ部分に取り付けられます。ブームセグメントの位置を合わせ、ヒンジ（軸）部分の隙間を埋める役割を果たします。

### ⚠️ 重要事項
これらの部品は、組み立て時および使用時に**大きな圧力**がかかります。以下の仕様に従い、厚い壁で印刷することを**強く推奨します**。壁の厚さが不十分な場合、部品が破損してブーム内部で詰まり、取り出せなくなる原因となります。

### 推奨印刷設定

| パラメータ | 値 |
|:---|:---|
| **素材** | PETG |
| **ノズル径** | 0.4mm |
| **積層ピッチ**  | 0.2mm |
| **壁の厚さ** | 5 層 |
| **上部レイヤー** | 6 層 |
| **底部レイヤー** | 5 層 |
| **充填密度** | 40% |
| **充填パターン** | クロスハッチ (Cross Hatch) |

### 配置とサポート
* **配置:** 大きな平らな面をプリントベッド側（下）に向け、凹面と凸面が上を向くように配置してください。
* **サポート:** **サポートを有効にする必要があります。**

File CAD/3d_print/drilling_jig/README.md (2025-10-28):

# Printing Instructions

[English](#english) | [中文 (Chinese)](#中文-chinese) | [Deutsche (German)](#deutsche-german) | [日本語 (Japanese)](#日本語-japanese)

---

## English

This directory contains two types of drilling jigs:
1.  **Driven Element Jig:** `driven_element_drill_jig_upper.step` & `driven_element_drill_jig_lower.step`
2.  **Parasitic Element Jig:** `element_drill_jig.step`

Please use the specific settings for each part.

### 1. Driven Element Jig
* **Parts:**
    * `driven_element_drill_jig_upper.step`
    * `driven_element_drill_jig_lower.step`
* **Purpose:** These two parts are used as a pair to clamp the bent driven element. They are held together tightly in a bench vise for drilling.
* **Note:** The parts will be under significant pressure from the vise.

#### Recommended Print Settings

| Parameter | Value |
|:---|:---|
| **Material** | PETG |
| **Nozzle Diameter** | 0.4mm |
| **Layer Height** | 0.2mm |
| **Wall Thickness**  | 4 Layers |
| **Top Layers** | 3 Layers |
| **Bottom Layers** | 3 Layers |
| **Infill Density**  | 25% |
| **Infill Pattern**  | Cross Hatch |

#### Orientation & Supports
* **Orientation:** Place the large flat side down on the print bed. The slanted/angled side should face upwards.
* **Supports:** **Not required.**

---

### 2. Parasitic Element Jig
* **Part:**
    * `element_drill_jig.step`
* **Purpose:** Used for drilling all other parasitic elements (reflectors and directors).
* **Note:** This jig is designed to be used with a drill bushing to protect the print from wear, as it will be used many times.

#### Recommended Print Settings

| Parameter | Value |
|:---|:---|
| **Material** | PETG |
| **Nozzle Diameter** | 0.4mm |
| **Layer Height** | 0.2mm |
| **Wall Thickness**  | 4 Layers |
| **Top Layers** | 4 Layers |
| **Bottom Layers** | 4 Layers |
| **Infill Density**  | 25% |
| **Infill Pattern**  | Cross Hatch |

#### Orientation & Supports
* **Orientation:** Place the slotted face down on the print bed. The countersink hole for the drill bushing should face upwards.
* **Supports:** **Not required.**

---
---

## 中文 (Chinese)

此文件夹包含两种类型的钻孔夹具：
1.  **激励振子夹具:** `driven_element_drill_jig_upper.step` & `driven_element_drill_jig_lower.step`
2.  **无源振子夹具:** `element_drill_jig.step`

请对不同零件使用对应的特定设置。

### 1. 激励振子钻孔夹具
* **零件:**
    * `driven_element_drill_jig_upper.step`
    * `driven_element_drill_jig_lower.step`
* **用途:** 这两个零件（上、下）配对使用，用于夹住弯曲成型的激励振子。使用时，它们会被老虎钳夹紧以进行钻孔。
* **注意:** 零件会承受来自老虎钳的较大压力。

#### 推荐打印参数

| 参数 | 数值 |
|:---|:---|
| **材料** | PETG |
| **喷嘴直径** | 0.4mm |
| **层高** | 0.2mm |
| **壁厚** | 4 层 |
| **顶部层数** | 3 层 |
| **底部层数** | 3 层 |
| **填充密度** | 25% |
| **填充图案** | 交叉层叠 (Cross Hatch) |

#### 打印方向与支撑
* **打印方向:** 将大平面朝下放置在打印床上，斜面朝上。
* **支撑:** **无须开启支撑。**

---

### 2. 无源振子钻孔夹具
* **零件:**
    * `element_drill_jig.step`
* **用途:** 用于钻孔所有其他的无源振子（反射器和引向器）。
* **注意:** 由于使用次数非常多，此夹具设计用于安装一个钻套，以保护打印件免受磨损。

#### 推荐打印参数

| 参数 | 数值 |
|:---|:---|
| **材料** | PETG |
| **喷嘴直径** | 0.4mm |
| **层高** | 0.2mm |
| **壁厚** | 4 层 |
| **顶部层数** | 4 层 |
| **底部层数** | 4 层 |
| **填充密度** | 25% |
| **填充图案** | 交叉层叠 (Cross Hatch) |

#### 打印方向与支撑
* **打印方向:** 将开缝面朝下放置在打印床上，用于安装钻套的沉孔朝上。
* **支撑:** **无须开启支撑。**

---
---

## Deutsche (German)

Dieses Verzeichnis enthält zwei Arten von Bohrlehren:
1.  **Bohrlehre für Erregerelement:** `driven_element_drill_jig_upper.step` & `driven_element_drill_jig_lower.step`
2.  **Bohrlehre für Parasitärelemente:** `element_drill_jig.step`

Bitte verwenden Sie die spezifischen Einstellungen für jedes Bauteil.

### 1. Bohrlehre für Erregerelement
* **Bauteile:**
    * `driven_element_drill_jig_upper.step`
    * `driven_element_drill_jig_lower.step`
* **Zweck:** Diese beiden Teile (oben und unten) werden als Paar verwendet, um das gebogene Erregerelement einzuklemmen. Sie werden zum Bohren fest in einen Schraubstock gespannt.
* **Hinweis:** Die Teile stehen unter erheblichem Druck durch den Schraubstock.

#### Empfohlene Druckeinstellungen

| Parameter | Wert |
|:---|:---|
| **Material** | PETG |
| **Düsendurchmesser** | 0.4mm |
| **Schichthöhe** | 0.2mm |
| **Wandstärke** | 4 Schichten |
| **Obere Schichten**  | 3 Schichten |
| **Untere Schichten** | 3 Schichten |
| **Fülldichte** | 25% |
| **Füllmuster** | Cross Hatch |

#### Ausrichtung & Stützstrukturen
* **Ausrichtung:** Legen Sie die große, flache Seite nach unten auf das Druckbett. Die abgeschrägte Seite sollte nach oben zeigen.
* **Stützstrukturen:** **Nicht erforderlich.**

---

### 2. Bohrlehre für Parasitärelemente
* **Bauteil:**
    * `element_drill_jig.step`
* **Zweck:** Wird zum Bohren aller anderen parasitären Elemente (Reflektoren und Direktoren) verwendet.
* **Hinweis:** Diese Lehre ist für die Verwendung mit einer Bohrbuchse ausgelegt, um den Druck vor Verschleiß zu schützen, da sie sehr oft verwendet wird.

#### Empfohlene Druckeinstellungen

| Parameter | Wert |
|:---|:---|
| **Material** | PETG |
| **Düsendurchmesser** | 0.4mm |
| **Schichthöhe** | 0.2mm |
| **Wandstärke** | 4 Schichten |
| **Obere Schichten**  | 4 Schichten |
| **Untere Schichten** | 4 Schichten |
| **Fülldichte** | 25% |
| **Füllmuster** | Cross Hatch |

#### Ausrichtung & Stützstrukturen
* **Ausrichtung:** Legen Sie die geschlitzte Seite nach unten auf das Druckbett. Die Senkbohrung für die Bohrbuchse sollte nach oben zeigen.
* **Stützstrukturen:** **Nicht erforderlich.**

---
---

## 日本語 (Japanese)

このディレクトリには2種類のドリルジグ（穿孔治具）が含まれています。
1.  **給電素子用ドリルジグ:** `driven_element_drill_jig_upper.step` & `driven_element_drill_jig_lower.step`
2.  **無給電素子用ドリルジグ:** `element_drill_jig.step`

各パーツに適した設定を使用してください。

### 1. 給電素子用ドリルジグ
* **パーツ:**
    * `driven_element_drill_jig_upper.step`
    * `driven_element_drill_jig_lower.step`
* **目的:** これら2つ（上部と下部）のパーツは、曲げ加工済みの給電素子を挟み込むためにペアで使用されます。穿孔する際、万力（バイス）で強く固定されます。
* **注意:** これらのパーツは万力によって大きな圧力を受けます。

#### 推奨印刷設定

| パラメータ | 値 |
|:---|:---|
| **素材** | PETG |
| **ノズル径** | 0.4mm |
| **積層ピッチ**  | 0.2mm |
| **壁の厚さ** | 4 層 |
| **上部レイヤー** | 3 層 |
| **底部レイヤー** | 3 層 |
| **充填密度** | 25% |
| **充填パターン** | クロスハッチ (Cross Hatch) |

#### 配置とサポート
* **配置:** 大きな平らな面をプリントベッド側（下）に向け、傾斜している面を上に向けてください。
* **サポート:** **不要です。**

---

### 2. 無給電素子用ドリルジグ
* **パーツ:**
    * `element_drill_jig.step`
* **目的:** 他のすべての無給電素子（反射器および導波器）の穿孔に使用します。
* **注意:** このジグは非常に多く使用されるため、ドリルブッシュ（ドリルガイド）を装着して印刷部品を摩耗から保護するように設計されています。

#### 推奨印刷設定

| パラメータ | 値 |
|:---|:---|
| **素材** | PETG |
| **ノズル径** | 0.4mm |
| **積層ピッチ**  | 0.2mm |
| **壁の厚さ** | 4 層 |
| **上部レイヤー** | 4 層 |
| **底部レイヤー** | 4 層 |
| **充填密度** | 25% |
| **充填パターン** | クロスハッチ (Cross Hatch) |

#### 配置とサポート
* **配置:** スリット（開口部）のある面をプリントベッド側（下）に向け、ドリルブッシュ用の皿穴（沈み穴）が上を向くように配置してください。
* **サポート:** **不要です。**

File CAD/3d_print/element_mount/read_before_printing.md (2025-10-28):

# Printing Instructions

[English](#english) | [中文 (Chinese)](#中文-chinese) | [Deutsche (German)](#deutsche-german) | [日本語 (Japanese)](#日本語-japanese)

---

## English

### Part
* `element_mount.step`

### Purpose
This part (element mount) is used to fix the parasitic elements (reflectors and directors) to the square boom.

### Note
This part is not under significant stress during use, so the printing requirements can be slightly relaxed.

### Recommended Print Settings

| Parameter | Value |
|:---|:---|
| **Material** | PETG |
| **Nozzle Diameter** | 0.4mm |
| **Layer Height** | 0.2mm |
| **Wall Thickness**  | 3 Layers |
| **Top Layers** | 4 Layers |
| **Bottom Layers** | 4 Layers |
| **Infill Density**  | 25% |
| **Infill Pattern**  | Cross Hatch |

### Orientation & Supports
* **Orientation:** Place the large flat face down on the print bed. This is the side where the grooves have a **fillet** (rounded edge). The side with the **chamfered** (angled) grooves should face upwards.
* **Supports:** **Not required.**

---

## 中文 (Chinese)

### 零件
* `element_mount.step`

### 用途
此零件 (振子扣具) 用于将无源振子 (反射器和引向器) 固定到主梁上。

### 注意
该零件在使用时不会承受太大的受力，因此打印参数要求可适当放宽。

### 推荐打印参数

| 参数 | 数值 |
|:---|:---|
| **材料** | PETG |
| **喷嘴直径** | 0.4mm |
| **层高** | 0.2mm |
| **壁厚** | 3 层 |
| **顶部层数** | 4 层 |
| **底部层数** | 4 层 |
| **填充密度** | 25% |
| **填充图案** | 交叉层叠 (Cross Hatch) |

### 打印方向与支撑
* **打印方向:** 将其大的平面朝下放置在打印床上 (即**凹槽带圆角**的一面朝下，**凹槽带倒角**的一面朝上)。
* **支撑:** **无须开启支撑。**

---

## Deutsche (German)

### Bauteil
* `element_mount.step`

### Zweck
Dieses Bauteil (Elementhalterung) wird verwendet, um die parasitären Elemente (Reflektoren und Direktoren) am quadratischen Boom zu befestigen.

### Hinweis
Dieses Teil ist im Gebrauch keiner nennenswerten Belastung ausgesetzt, daher können die Druckanforderungen leicht gelockert werden.

### Empfohlene Druckeinstellungen

| Parameter | Wert |
|:---|:---|
| **Material** | PETG |
| **Düsendurchmesser** | 0.4mm |
| **Schichthöhe** | 0.2mm |
| **Wandstärke** | 3 Schichten |
| **Obere Schichten**  | 4 Schichten |
| **Untere Schichten** | 4 Schichten |
| **Fülldichte** | 25% |
| **Füllmuster** | Cross Hatch |

### Ausrichtung & Stützstrukturen
* **Ausrichtung:** Legen Sie die große, flache Seite nach unten auf das Druckbett. Dies ist die Seite, auf der die Nuten eine **Abrundung** (Fillet) aufweisen. Die Seite mit den **abgeschrägten** (Chamfer) Nuten sollte nach oben zeigen.
* **Stützstrukturen:** **Nicht erforderlich.**

---

## 日本語 (Japanese)

### パーツ
* `element_mount.step`

### 目的
このパーツ (エレメントマウント) は、無給電素子 (反射器と導波器) を角型ブームに取り付けるために使用されます。

### 注意
このパーツには使用時に大きな負荷がかからないため、印刷設定の要件は比較的緩やかです。

### 推奨印刷設定

| パラメータ | 値 |
|:---|:---|
| **素材** | PETG |
| **ノズル径** | 0.4mm |
| **積層ピッチ**  | 0.2mm |
| **壁の厚さ** | 3 層 |
| **上部レイヤー** | 4 層 |
| **底部レイヤー** | 4 層 |
| **充填密度** | 25% |
| **充填パターン** | クロスハッチ (Cross Hatch) |

### 配置とサポート
* **配置:** 大きな平らな面をプリントベッド側（下）に置いてください。これは、溝が**フィレット**（丸みを帯びた角）になっている面です。**面取り**（角度のついた角）が施されている溝のある面が上を向くよう配置します。
* **サポート:** **不要です。**

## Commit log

2025-10-26 added step for booms and masts
    [stacking_horizontal_spreader.step, stacking_vertical_mast.step, yagi_boom_front.step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]
2025-10-26 added step for 3d printing parts
    [boom_hinge_cap_front.step, boom_hinge_cap_rear.step, boom_sleeve.step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]
2025-10-26 Revise README for clarity and additional details
    Updated the README to improve clarity and detail about the antenna design, including usability confirmation and repository contents.
2025-10-26 Enhance README with design and optimization details
    Added detailed electrical design and mechanical optimizations sections for the 14-element Yagi antenna project.
2025-10-26 added element mount step file
    [element_mount.step]
2025-10-27 Update README with BOM and link enhancements
    Added a partial Bill of Materials (BOM) and updated references with links.
2025-10-27 完善 README_zh 文件，增加项目详细信息
    更新了 README_zh 文件，增加了关于便携式 432MHz EME 八木天线阵列的详细信息，包括项目简介、设计理念、技术规格、物料清单等内容。
2025-10-27 Add mounting system details and element mount design to README
2025-10-27 Update BOM details in README and Chinese translation
2025-10-27 Enhance README files with detailed CAD directory structure and component descriptions
2025-10-27 Add theoretical performance metrics for Yagi antenna in README and Chinese translation
2025-10-28 Add printing instructions for Yagi antenna components in multiple languages
2025-10-28 Add detailed printing instructions for drilling jigs in multiple languages
2025-10-28 Add multi-language printing instructions for element mount part
2025-10-28 Add multi-language printing instructions for feed box components
2025-10-28 Rename and consolidate printing instructions into a comprehensive README with multi-language support
2025-10-28 Add detailed 3D printing guidelines and multi-lingual instructions in README files
2025-10-29 Add comprehensive antenna fabrication and assembly guide with multi-language support
2025-10-29 Add detailed assembly instructions and guide links in English and Chinese
2025-10-29 Add multi-language support for 3D printing and aluminum processing guidelines in German and Japanese README files
